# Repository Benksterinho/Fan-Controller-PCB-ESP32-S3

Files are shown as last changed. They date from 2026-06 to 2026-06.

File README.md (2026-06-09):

# JumboNAS Fan Controller PCB (ESP32-S3, Rev A)

This repository contains the hardware design and supporting documentation for a maker-friendly 4-wire PWM fan controller board built around ESP32-S3.

The PCB is intended for projects that need to power and control a standard 12 V PC fan, read tach feedback, and optionally show status on an SPI display, with room for future telemetry and expansion.

## What This Board Is For

- Controlling one 12 V 4-wire PWM fan from an ESP32-S3.
- Reading fan tach pulses for RPM measurement.
- Running standalone logic in CircuitPython on ESP32-S3.
- Driving an external ST7789 SPI display header.
- Exposing safe optional GPIOs through an expansion header.

Typical use cases:

- DIY NAS or homelab cooling controller.
- Smart enclosure or cabinet fan controller.
- General embedded fan-control bring-up platform.

## Hardware Overview

- Input power: 19-24 V DC recommended.
- Reverse polarity and surge protection at board input.
- 12 V rail: K7812 SIP module regulator.
- 3.3 V rail: K7803 SIP module regulator.
- Controller: ESP32-S3-WROOM-1-N16R8.
- Fan interface: Intel-style 4-pin PWM fan header.
- Programming/debug: external 1x6 UART header.

Input note:

- 19-24 V is the supported operating range for Rev A.
- 17-18 V may work in some conditions but is not guaranteed with the current Schottky protection stage.

## Project Status

Rev A is an actively developed hardware revision focused on first-pass manufacturability and bring-up reliability.

Current priorities:

- Keep BOM practical for PCBWay/LCSC assembly.
- Keep board size within cost-efficient limits (target under 99 x 99 mm).
- Use conservative, proven power-stage choices for a first hardware spin.

## Repository Layout

- [docs](docs): design rationale, requirements, BOM, sourcing, and build notes.
- [docs/sheet-specs](docs/sheet-specs): per-subsheet intent and signal definitions.
- [hardware/kicad/fan_controller_revA](hardware/kicad/fan_controller_revA): KiCad project files for Rev A.
- [firmware](firmware): reserved area for CircuitPython firmware and bring-up utilities.

## If You Want To Build One

1. Read [docs/requirements.md](docs/requirements.md) for scope and constraints.
2. Read [docs/architecture.md](docs/architecture.md) for system-level decisions.
3. Review [docs/bom-revA.csv](docs/bom-revA.csv) and [docs/bom-revA-status.md](docs/bom-revA-status.md).
4. Open the KiCad project in [hardware/kicad/fan_controller_revA](hardware/kicad/fan_controller_revA).
5. Follow manufacturing notes in [docs/pcbway-assembly.md](docs/pcbway-assembly.md).

## Key Docs

- [docs/architecture.md](docs/architecture.md)
- [docs/requirements.md](docs/requirements.md)
- [docs/current-budget.md](docs/current-budget.md)
- [docs/schematic-plan.md](docs/schematic-plan.md)
- [docs/gpio-map.md](docs/gpio-map.md)
- [docs/bom-revA.csv](docs/bom-revA.csv)
- [docs/bom-revA-status.md](docs/bom-revA-status.md)
- [docs/sourcing-checklist.md](docs/sourcing-checklist.md)
- [docs/pcbway-assembly.md](docs/pcbway-assembly.md)

## Safety And Scope

This is a low-voltage maker hardware project and is provided as-is. Validate thermal behavior, fan startup behavior, and input transient behavior in your own enclosure and power environment before unattended use.

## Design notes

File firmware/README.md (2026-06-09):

# Firmware Area

This folder is reserved for CircuitPython firmware, bring-up scripts, and test utilities for the ESP32-S3 controller.

Initial firmware goals:

- Fan PWM control
- Tach readback
- Wi-Fi telemetry receiver
- ST7789 display updates
- Optional expansion-header support

## Bring-Up Notes And Gotchas

### PWM Inversion Behavior

Fan PWM and display backlight use NPN open-collector stages, so logic is inverted at the controlled node.

```c
fan_duty = 1.0f - desired_speed;
bl_duty = 1.0f - desired_brightness;
```

### GPIO Warnings

- GPIO35/GPIO36/GPIO37 are reserved on N16R8 modules (internal PSRAM interface) and must not be reassigned.
- GPIO46 must not be driven HIGH during reset; doing so can force Download Boot instead of normal SPI boot.
- GPIO19/GPIO20 correspond to native USB D-/D+ on ESP32-S3; using them on expansion functions blocks future native USB reuse.

### External UART Wiring Reminder

Cross TX/RX between adapter and board:

- Adapter RX -> Board UART_TX
- Adapter TX -> Board UART_RX

This crossover is expected and is a common bring-up mistake.

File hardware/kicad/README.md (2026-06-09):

# KiCad Project Area

This folder contains KiCad-related project notes and guides for the fan controller.

## Active project folder

- `fan_controller_revA/`

## Inside `fan_controller_revA/`

- no active schematic files are currently committed
- how-to guides for rebuilding capture order and net naming
- local README with capture order and shared net names

## Next step

Create a fresh KiCad schematic project and capture each subsystem in the documented order.

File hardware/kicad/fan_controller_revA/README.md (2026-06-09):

# Fan Controller Rev A - KiCad Notes

Generated schematic files were removed. This folder now serves as the capture guide and naming reference.

## Files

- howto_subsheets/ (step-by-step capture guides)
- pcb_layout/ (subsheet-specific PCB Editor placement and routing guides)
- README.md (capture order and shared net naming)

## Capture Order

1. InputProtection
2. Power12V
3. Power3V3
4. ESP32S3Core
5. Fan4Wire
6. DisplayHeader_ST7789
7. ExternalProgrammingHeader
8. TestPoints
9. OptionalExpansionHeader

## Global Net Names To Reuse

- VIN_PROTECTED
- 12V
- 3V3
- GND
- EN_RESET
- GPIO0_BOOT
- UART_TX
- UART_RX
- FAN_PWM
- FAN_TACH
- SPI_SCK
- SPI_MOSI
- DISP_CS
- DISP_DC
- DISP_RST

## Notes

- Recreate all schematic sheets from docs/sheet-specs/*.md.
- Keep net names aligned with this README to avoid cross-sheet drift.
- Onboard rail telemetry is deferred from Rev A; add it only in a later revision if bring-up shows a real need.

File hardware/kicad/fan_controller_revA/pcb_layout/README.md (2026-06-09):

# PCB Layout Subsheet Guide Index

This folder contains PCB Editor placement/routing guides mapped to the schematic subsheets.

Use this flow after every schematic update:
1. In Schematic Editor, run Update PCB from Schematic.
2. In PCB Editor, refresh ratsnest and run DRC after major placement steps.
3. Work one subsheet cluster at a time using the matching file below.

## Absolute beginner quick start
1. Open PCB Editor and enable the right sidebar panels so Search/Filter tools are visible.
2. Open 00_SheetSelection_AfterUpdate.md and select one subsheet cluster first.
3. Move selected footprints with M, rotate with R, and place with left click.
4. Start routing with X, click to place corners, and double-click to finish a track.
5. Press B to refill copper zones after major routing edits.
6. Run DRC from the Inspect menu after each phase.

## Common PCB Editor shortcuts
1. M: Move selected footprint or item.
2. R: Rotate selected footprint or item.
3. E: Open properties for selected item.
4. Del: Delete selected item.
5. X: Route tracks.
6. V: Drop a via while routing.
7. B: Refill all zones.
8. Ctrl+S: Save.

If a shortcut differs in your KiCad version, open Preferences -> Hotkeys and search by command name.

## Files
- 00_SheetSelection_AfterUpdate.md
- 01_InputProtection_layout.md
- 02_Power12V_layout.md
- 03_Power3V3_layout.md
- 04_ESP32S3Core_layout.md
- 05_Fan4Wire_layout.md
- 06_DisplayHeader_ST7789_layout.md
- 07_ExternalProgrammingHeader_layout.md
- 08_TestPoints_layout.md
- 10_OptionalExpansionHeader_layout.md
- 11_EndToEnd_PCB_Layout_Checklist.md

## Recommended layout order
1. 11_EndToEnd_PCB_Layout_Checklist.md
2. 00_SheetSelection_AfterUpdate.md
3. 01_InputProtection_layout.md
4. 02_Power12V_layout.md
5. 03_Power3V3_layout.md
6. 04_ESP32S3Core_layout.md
7. 05_Fan4Wire_layout.md
8. 06_DisplayHeader_ST7789_layout.md
9. 07_ExternalProgrammingHeader_layout.md
10. 08_TestPoints_layout.md
11. 10_OptionalExpansionHeader_layout.md

## Placement strategy summary
1. Place power entry and protection near board input edge.
2. Keep regulator loops compact before placing digital logic.
3. Place ESP32 module for RF keepout first, then fan/display/programming connectors.
4. Reserve board edges for external connectors and test points.
5. Route high-current and noisy nets before sensitive digital feedback nets.

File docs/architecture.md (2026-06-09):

# Architecture

## Power

- Input protection front-end (screw terminal → reverse-polarity diode → fuse → VIN_PROTECTED)
- 12V rail: K7812-1000R3 non-isolated module regulator, SIP-3, 1A — no discrete magnetics or feedback network
- 3.3V rail: EVISUN K7803-1000R3 non-isolated module regulator, SIP-3, 1A — no discrete magnetics or feedback network
- Both modules (K7812 for 12V, K7803 for 3.3V) source directly from VIN_PROTECTED (19-24V supported input) in parallel. This avoids cascading and ensures each rail is independently regulated from the protected input. With the current Schottky reverse-polarity stage, 17-18V operation is not guaranteed.
- Decoupling caps on input and output of each module; no other external components required
- First-pass current budget: 12V rail 1A continuous, 3.3V rail 1A continuous with Wi-Fi burst headroom
- Module choice rationale: eliminates inductor/diode/feedback layout risk on Rev A; priority is first-pass success

## Control

- ESP32-S3-WROOM-1-N16R8 as the preferred module choice for Rev A if PCBWay sponsorship and sourcing allow it
- 16 MB flash and 8 MB PSRAM for CircuitPython headroom, buffer space, and future firmware growth
- Use the standard Espressif module footprint and keep the antenna keep-out clear
- If cost or sourcing pressure is significant, downgrade to an ESP32-S3 WROOM-1 PSRAM variant with less flash rather than changing the module family
- ESP32-S3 module with stable boot/reset wiring
- Fan PWM driven as open-drain compatible control
- Tach input protected and level-safe for 3.3V GPIO

## Interfaces

- External UART programming header (1x6, 2.54mm) for flashing and logging via external downloader
- External SPI display header
- Optional expansion header using only safe GPIOs

## Future Revision Note

- Onboard rail telemetry is intentionally deferred from Rev A. Test points cover bring-up needs, and a telemetry block can be added in a later revision if real diagnostic value appears.

## Layout rules

- Keep the board below the pricing threshold by budgeting to a smaller outline early
- Place power modules with input/output decoupling caps within 10mm of module pins
- Keep switch-node concerns eliminated — modules have no exposed switching nodes
- Reserve clear access for screw terminal and external programming header
- Antenna keep-out clear of copper under ESP32-S3 module

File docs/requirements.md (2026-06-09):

# Requirements

## Core

- Input: 19-24V DC supported for Rev A with current Schottky reverse-polarity stage; 17-18V operation is not guaranteed
- Outputs: 12V fan rail and 3.3V logic rail
- Controller: ESP32-S3 running CircuitPython
- Fan: one 4-pin PWM fan channel with tach feedback
- Display: external 3.3V SPI ST7789 header
- Connectivity: Wi-Fi telemetry from a Linux host

## Optional

- Maker expansion header for safe unused ESP32-S3 GPIOs

## Constraints

- Board outline should remain below 99x99 mm
- Prefer parts with strong public reference designs
- Prefer full PCBWay assembly with no user soldering

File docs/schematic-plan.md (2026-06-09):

# Schematic Plan

## Current Lock State

- LOCKED: ESP32S3Core (module selection, EN/BOOT network, and exported control nets)
- LOCKED: Fan4Wire (connector choice, PWM sink stage, tach conditioning, and root integration)
- LOCKED: DisplayHeader_ST7789 (live-verified sourcing for J_DISP, 33R damping network, optional MISO link, local bypass, and BL open-collector stage)
- LOCKED: ExternalProgrammingHeader (1x6 external UART/programming header with EN/GPIO0 control nets)
- VALIDATED: Fresh root ERC passes with 0 errors on current schematic set

## Top-Level KiCad Hierarchy

- `fan_controller_revA` as the root sheet
- `InputProtection` with [InputProtection spec](sheet-specs/InputProtection.md)
- `Power12V` with [Power12V spec](sheet-specs/Power12V.md)
- `Power3V3` with [Power3V3 spec](sheet-specs/Power3V3.md)
- `ESP32S3Core` with [ESP32S3Core spec](sheet-specs/ESP32S3Core.md)
- `Fan4Wire` with [Fan4Wire spec](sheet-specs/Fan4Wire.md)
- `DisplayHeader_ST7789` with [DisplayHeader_ST7789 spec](sheet-specs/DisplayHeader_ST7789.md)
- `ExternalProgrammingHeader` with [ExternalProgrammingHeader spec](sheet-specs/ExternalProgrammingHeader.md)
- `OptionalExpansionHeader` with [OptionalExpansionHeader spec](sheet-specs/OptionalExpansionHeader.md)
- `TestPoints` with [TestPoints spec](sheet-specs/TestPoints.md)

## Net Flow

1. `J1` input connector enters `InputProtection`
2. Protected VIN feeds `Power12V` and `Power3V3` in parallel
3. Regulated 12V feeds the fan power pin path
4. Regulated 3.3V feeds `ESP32S3Core`, `DisplayHeader_ST7789`, and safe expansion power
5. `ESP32S3Core` controls `Fan4Wire` via PWM and reads tach back from the fan interface
6. `ESP32S3Core` talks to `ExternalProgrammingHeader` for flashing/logging and to `DisplayHeader_ST7789` via SPI
7. `OptionalExpansionHeader` stays decoupled from the mandatory control path except for shared 3.3V, GND, and safe GPIO nets
8. `TestPoints` taps only stable rails and debug nets; it must not alter control behavior

## Sheet Boundaries

- `InputProtection`: connector, reverse protection, fuse, TVS, input filtering
- `Power12V`: K7812 module stage, input decoupling, 12V rail distribution
- `Power3V3`: K7803 module stage, input/output decoupling, 3.3V rail distribution
- `ESP32S3Core`: module, boot/reset, UART0, and mandatory control GPIO assignment
- `Fan4Wire`: 4-pin fan header, PWM open-drain drive, tach input conditioning, fan power pin
- `DisplayHeader_ST7789`: SPI display header and any series damping parts
- `ExternalProgrammingHeader`: external downloader interface exposing UART/EN/BOOT plus 3V3/GND
- `OptionalExpansionHeader`: safe spare GPIO header with per-line protection
- `TestPoints`: labeled rail and debug points for bring-up

## Capture Order

1. Lock `InputProtection` and power entry
2. Capture `Power12V` around the chosen reference layout
3. Capture `Power3V3` around the chosen reference layout
4. Capture `ESP32S3Core` and boot/reset wiring
5. Add `Fan4Wire`
6. Add `DisplayHeader_ST7789`
7. Add `ExternalProgrammingHeader`
8. Add `TestPoints`
9. Add `OptionalExpansionHeader` only after the mandatory path is stable

## Archived Sheet Note

- `ProgrammingUSB` is retained in the repository for reference only and is not part of the active Rev A signal path.

## Future Revision Note

- Onboard rail telemetry is deferred from Rev A. If bring-up or long-term diagnostics show a real need, add it in a later revision rather than reserving GPIOs and BOM lines now.

## Rules

- Do not use unvetted values for module-decoupling passives
- Keep module input/output decoupling close to module pins per datasheet
- Keep all user-facing headers clear of boot-strap pins and other sensitive ESP32-S3 lines
- Make sure every required part can be assembled by PCBWay without end-user soldering
- Use subsheets to review and lock one subsystem at a time instead of capturing the entire board as one block

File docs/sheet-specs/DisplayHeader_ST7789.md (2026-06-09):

# Sheet Spec: DisplayHeader_ST7789

**KiCad sheet:** `DisplayHeader_ST7789`  
**Purpose:** 2.54mm pin header for ST7789 SPI display module, series damping resistors, and display reset/backlight lines.  
**Input nets:** `3V3`, `GND`, `SPI_SCK`, `SPI_MOSI`, `DISP_CS`, `DISP_DC`, `DISP_RST`, `DISP_BL` (all from ESP32S3Core)  
**Connector output:** J_DISP — 8-pin 2.54mm right-angle through-hole header

---

## Display Module Compatibility

Target: generic ST7789 SPI display module (1.3", 1.54", or 2.0" breakout boards commonly sold as "ST7789 240×240" or "ST7789V 240×320").

**Typical ST7789 breakout pinout (8-pin, most common layout):**

| Pin | Label | Function |
|-----|---|---|
| 1 | GND | Ground |
| 2 | VCC | 3.3V power |
| 3 | SCL / SCK | SPI clock |
| 4 | SDA / MOSI | SPI data in |
| 5 | RES / RST | Hardware reset (active low) |
| 6 | DC / RS | Data/Command select |
| 7 | CS | Chip select (active low) |
| 8 | BLK / BL | Backlight enable |

**Note:** Pin order varies across ST7789 breakout vendors. The header is a pass-through — users plug their specific module. Label pins clearly in silk screen. Optional: provide a 2-row pinout label on silkscreen next to J_DISP.

---

## Connector (J_DISP)

| Parameter | Value |
|---|---|
| Type | 2.54mm pitch, 1x8 male header, right-angle, through-hole |
| Pins | 8 |
| PCBWay | THT, wave-solderable |
| Notes | No user soldering — PCBWay assembles. Rev A uses right-angle for lower vertical profile and side cable exit. |

---

## Series Damping Resistors

SPI signal lines should have series damping resistors to reduce ringing on fast edges (ST7789 can run at >20MHz SPI clock).

| Net | Resistor | Value | Package | Notes |
|-----|---|---|---|---|
| SPI_SCK | R_SCK | 33Ω | 0603 | Between ESP32 GPIO6 and J_DISP SCL pin |
| SPI_MOSI | R_MOSI | 33Ω | 0603 | Between ESP32 GPIO7 and J_DISP SDA pin |
| DISP_CS | R_CS | 33Ω | 0603 | Between ESP32 GPIO10 and J_DISP CS pin |
| DISP_DC | R_DC | 33Ω | 0603 | Between ESP32 GPIO9 and J_DISP DC pin |
| DISP_RST | R_RST | 33Ω | 0603 | Between ESP32 GPIO16 and J_DISP RES pin |

Rev A decision: SPI_MISO is not implemented. Leave any display-module MISO/SDO pin unconnected.

33Ω is a standard signal integrity value — low enough to not cause significant voltage drop, high enough to damp reflections at board edge.

---

## Power Lines to Header

| Header Pin | Net | Notes |
|---|-----|---|
| VCC | 3V3 | Directly from 3V3 rail; add 100nF bypass cap at header pin |
| GND | GND | Direct return |

**Local bypass cap:**
- 100nF MLCC, 10V, 0402, at J_DISP VCC pin.

Some ST7789 modules have a 3.3V regulator onboard and accept 5V VCC. This header provides 3.3V — confirm display module accepts 3.3V VCC (most bare ST7789 modules do).

## Rev A Verified Sourcing Picks

| Function | LCSC | Verified part |
|---|---|---|
| J_DISP | C32713267 | hanxia HX PZ2.54-1x8P WZ, 2.54mm single-row 1x8 male right-angle through-hole header |
| R_SCK / R_MOSI / R_CS / R_DC / R_RST | C2909394 | FOJAN FRC0603F33R0TS, 33Ω ±1% 0603 thick-film resistor |
| C_DISP_VCC | C307331 | Samsung CL05B104KB54PNC, 100nF 50V X7R 0402 MLCC |
| Q_BL | C181119 | MMBT3904 NPN SOT-23 for open-collector backlight sink |
| R_BL_BASE | C4190 | 2.2kΩ 0603 base resistor for Q_BL |
| R_BL_PD | C25803 | 100kΩ 0603 base pull-down for Q_BL |

---

## Backlight (BLK) Pin

Use the same open-collector approach as the fan PWM stage so the ESP32 does not source backlight current directly.

| Node | Implementation |
|---|---|
| Control input | `DISP_BL` from ESP32 GPIO40 into `R_BL_BASE` (2.2kΩ) to `Q_BL` base |
| Base default state | `R_BL_PD` (100kΩ) from `Q_BL` base to GND |
| Sink stage | `Q_BL` MMBT3904: emitter to GND, collector to J_DISP BLK pin |
| Backlight output | J_DISP BLK pin is driven by open-collector sink for on/off and PWM dimming |

**Firmware note:** This stage is inverting. Higher PWM duty at GPIO40 results in stronger sink action on BLK.

---

## Net Summary

| Net | Direction | Header Pin |
|-----|---|---|
| GND | Input | J_DISP pin 1 |
| 3V3 | Input | J_DISP pin 2 |
| SPI_SCK (via R_SCK) | Output | J_DISP pin 3 |
| SPI_MOSI (via R_MOSI) | Output | J_DISP pin 4 |
| DISP_RST (via R_RST) | Output | J_DISP pin 5 |
| DISP_DC (via R_DC) | Output | J_DISP pin 6 |
| DISP_CS (via R_CS) | Output | J_DISP pin 7 |
| DISP_BL (to Q_BL base via R_BL_BASE) | Output | Internal driver input |
| BLK (from Q_BL collector) | Output | J_DISP pin 8 |

---

## Layout Rules

1. **Damping resistors placed close to J_DISP**, between header and trace to ESP32 — correct side of the resistor should face the source (ESP32 side), termination faces the load (header).
2. **J_DISP placed on board edge or accessible face** for clean cable routing to display.
3. **Bypass cap at VCC pin** — immediately adjacent to J_DISP.
4. **SPI traces** should not run parallel to module power paths or fan 12V high-current traces. Keep at least 3mm separation where practical.
5. **RST trace** must not float — routed from ESP32 GPIO16 through R_RST to header pin. No pull-up needed (ESP32 drives it; display module typically has internal pull-up).

---

## Checklist Before KiCad Capture

- [ ] Confirm target display module pinout (measure or check datasheet for specific module)
- [ ] Verify right-angle connector pin-1 orientation matches silkscreen and cable pin order
- [ ] Verify display MISO/SDO pin remains NC in Rev A
- [ ] Verify BLK input behavior for your selected module (logic enable vs direct LED path)

---

## Dependencies

- **Depends on:** `ESP32S3Core` (SPI + CS/DC/RST nets), `Power3V3` (3V3 net)
- **Consumed by:** none (leaf sheet)

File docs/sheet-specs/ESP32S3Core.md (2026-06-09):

# Antenna Keep-Out Guidance (Critical)

**ESP32-S3-WROOM-1 PCB antenna keep-out requirements (for layout):**
- **No copper pours, traces, or fills** under the antenna section of the module (top 3.5mm × 18mm region; see module datasheet Figure 7).
- **No vias, test points, or silkscreen** in the keep-out zone.
- **No metal objects within 3mm** of antenna edges in the horizontal plane (including mounting hardware, shields, or connectors).
- **Place module at board edge** so antenna overhangs or is near the edge, per Espressif hardware design guidelines.
- **In KiCad:**
	- Draw a keep-out zone on the top copper, top mask, and top silkscreen layers for the antenna region.
	- Add a board edge keep-out annotation and a note in the layout file: "ESP32 antenna keep-out: no copper, no traces, no vias, no silkscreen, no test points."
	- Confirm keep-out is respected in DRC and final Gerbers.

# Sheet Spec: ESP32S3Core

**KiCad sheet:** `ESP32S3Core`  
**Purpose:** ESP32-S3 module mounting, boot/reset network, decoupling, GPIO assignment, and strapping pin safety.  
**Input nets:** `3V3`, `GND`  
**Output/exposed nets:** `UART_TX`, `UART_RX`, `GPIO0_BOOT`, `EN_RESET`, plus all GPIO signal nets to downstream sheets.  
**Reference:** ESP32-S3-WROOM-1 datasheet (Espressif DS0003), ESP32-S3 Technical Reference Manual

---

## Module Selection

| Parameter | Value |
|---|---|
| Module | ESP32-S3-WROOM-1-N16R8 (preferred) |
| Flash | 16MB external (N16) |
| PSRAM | 8MB Octal (R8) — required for CircuitPython heap |
| Antenna | On-module PCB antenna (no external RF components needed) |
| Package | SMD castellated edge, 2.54mm pitch |
| Footprint | ESP32-S3-WROOM-1 standard (52 pins) |
| Fallback | ESP32-S3-WROOM-1-N8R8 (8MB flash, same footprint) |

**Critical:** Do not substitute ESP32-S3-MINI — different footprint. Do not use ESP32-S3 bare die (requires RF layout expertise).

---

## Power Supply Pins

| Module pin | Net | Decoupling |
|---|-----|---|
| 3V3 (pin 2) | 3V3 | 10µF + 100nF MLCC at pin, on this sheet |
| GND (pins 1, 40, 41) | GND | All connected to ground plane |
| GND (EP / thermal pad) | GND | If exposed — solder to ground copper |

**Decoupling capacitors:**
- 1× 10µF MLCC, 10V, 0805, close to pin 2
- 1× 100nF MLCC, 10V, 0402, as close as possible to pin 2

These are in addition to any bulk cap on the 3V3 rail from Power3V3. Module datasheet requires local decoupling.

---

## Strapping Pins — Mandatory Safety Rules

Strapping pins determine boot mode and peripheral mapping at power-on. They are sampled once at reset. Wrong states = broken firmware uploads or non-boot.

| GPIO | Strapping Function | Required State | Implementation |
|---|---|---|---|
| GPIO0 | Download mode vs normal boot | HIGH = normal boot; LOW = download mode | 10kΩ pullup to 3V3; BOOT button pulls to GND |
| GPIO3 | JTAG source selection | HIGH = USB Serial/JTAG selected for deterministic behavior | 10kΩ pullup to 3V3 (`R_JTAG`), no functional load on net |
| GPIO45 | VDD_SPI voltage config | LOW = 3.3V (correct for this board) | 10kΩ pulldown to GND or leave at module default (confirm module default via datasheet §4.4) |
| GPIO46 | ROM messages | HIGH = enabled; LOW = suppressed | Leave at module default (internal pulldown); do not drive |

**Rules:**
- GPIO0, GPIO3, GPIO45, GPIO46 must NOT be routed to expansion headers or load circuits.
- GPIO0 is shared with BOOT button — no other load on this net except the 10kΩ pullup, external programming control path, and the BOOT button.
- Strapping pins are sampled at EN (reset) rising edge. Boot button footprint must short GPIO0 to GND.

---

## Boot/Reset Network

### EN (Reset) Pin
| Component | Value | Notes |
|---|---|---|
| R_EN | 10kΩ | Pullup from EN to 3V3 |
| C_EN | 1uF, 0603 | EN to GND — recommended typical value for clean power-on reset with 10k pull-up |
| RESET button | Momentary NO pushbutton | Shorts EN to GND via 0Ω (direct), footprint on board |
| EN_RTS | From ExternalProgrammingHeader sheet | External programmer reset control drives EN_RESET (active-low), with on-board RESET button as manual fallback |

External programming control wiring:
- Reset control line → EN_RESET (active-low)
- Boot control line → GPIO0_BOOT (active-low)

The active Rev A path is external via the `ExternalProgrammingHeader` sheet. Manual BOOT and RESET buttons remain valid for flashing.

### BOOT (Download Mode) Pin
| Component | Value | Notes |
|---|---|---|
| R_BOOT | 10kΩ | Pullup from GPIO0 to 3V3 |
| BOOT button | Momentary NO pushbutton | Shorts GPIO0 to GND |

Do not add a mandatory capacitor from GPIO0 to GND in Rev A. If a footprint is reserved for experiments, keep it DNP by default so it does not interfere with the Espressif auto-program timing.

---

## GPIO Assignments

### Used GPIOs (assigned on this sheet, nets exposed to other sheets)

| GPIO | Net name | Function | Destination sheet |
|---|---|---|---|
| GPIO4 | FAN_TACH | Tachometer input | Fan4Wire |
| GPIO5 | FAN_PWM | 25kHz PWM output (LEDC) | Fan4Wire |
| GPIO6 | SPI_SCK | SPI clock for display | DisplayHeader_ST7789 |
| GPIO7 | SPI_MOSI | SPI MOSI for display | DisplayHeader_ST7789 |
| GPIO9 | DISP_DC | Display D/C (data/command) | DisplayHeader_ST7789 |
| GPIO10 | DISP_CS | Display chip select | DisplayHeader_ST7789 |
| GPIO16 | DISP_RST | Display reset | DisplayHeader_ST7789 |
| GPIO40 | DISP_BL | Display backlight enable/PWM | DisplayHeader_ST7789 |
| GPIO43 | UART_TX | UART0 TX to external downloader | ExternalProgrammingHeader |
| GPIO44 | UART_RX | UART0 RX from external downloader | ExternalProgrammingHeader |

### Reserved / Do Not Use
| GPIO | Reason |
|---|---|
| GPIO11–GPIO15 | Internal to module (Octal PSRAM interface on N16R8) |
| GPIO35–GPIO37 | Internal to module on N16R8 variant; do not assign externally |
| GPIO0 | Strapping pin (BOOT) |
| GPIO3 | Strapping pin (JTAG) |
| GPIO45 | Strapping pin (VDD_SPI) |
| GPIO46 | Strapping pin (ROM messages) |

### Available for Expansion Header (OptionalExpansionHeader sheet)
Remaining free GPIOs after above assignments:
Safe candidates: GPIO1, GPIO2, GPIO17, GPIO18, GPIO19, GPIO20, GPIO21, GPIO38, GPIO39, GPIO41, GPIO42.

---

## Antenna Keep-Out Zone

The ESP32-S3-WROOM-1 PCB antenna extends from the top edge of the module.

**Keep-out requirements:**
- No copper pours, traces, or fills under the antenna section of the module (approximately the top 3.5mm × 18mm region per module datasheet Figure 7).
- No metal objects within 3mm of antenna edges in the horizontal plane.
- Module should be placed at board edge so antenna overhangs or is near the edge, per Espressif hardware design guidelines (ESP32-S3 Hardware Design Guidelines, Section 3).

**KiCad implementation:** Add a board edge keep-out zone annotation. Place module at board edge.

---

## Decoupling Summary (this sheet)

| Ref | Value | Package | Net | Placement |
|-----|---|---|-----|---|
| C_3V3_10U | 10µF MLCC, 10V | 0805 | 3V3 | At module VDD pin |
| C_3V3_100N | 100nF MLCC, 10V | 0402 | 3V3 | At module VDD pin, closer than 10µF |
| R_EN | 10kΩ | 0603 | EN to 3V3 | Near module |
| C_EN | 1uF | 0603 | EN to GND | Near module |
| R_BOOT | 10kΩ | 0603 | GPIO0 to 3V3 | Near module |
| SW_RESET | Tactile pushbutton | SMD, maker-friendly footprint | EN to GND | Panel edge |
| SW_BOOT | Tactile pushbutton | SMD, maker-friendly footprint | GPIO0 to GND | Panel edge |

---

## Net Boundaries (Sheet Interface)

**Inputs to this sheet:**
- `3V3` — from Power3V3
- `GND`

**Outputs / signals exposed at sheet boundary:**
- `UART_TX`, `UART_RX` → ExternalProgrammingHeader
- `EN_RESET` → ExternalProgrammingHeader
- `GPIO0_BOOT` → ExternalProgrammingHeader
- `FAN_PWM`, `FAN_TACH` → Fan4Wire
- `SPI_SCK`, `SPI_MOSI`, `DISP_CS`, `DISP_DC`, `DISP_RST`, `DISP_BL` → DisplayHeader_ST7789
- Free GPIOs → OptionalExpansionHeader

---

## Layout Rules

1. **Module placed at or near PCB edge** so antenna overhangs or clears board copper per keep-out rule.
2. **Boot/reset buttons on panel-accessible edge** — user must be able to press them for firmware updates.
3. **UART RX→TX/TX→RX** crossing must not create long loops — keep UART traces short from module to external programming header.
4. **Decoupling caps** placed as close as possible to VDD pin (under or adjacent to module).
5. **GPIO traces** for fan PWM, SPI, and UART should be kept away from module power routing and fan 12V high-current paths — minimum 3mm separation where practical.
6. **No vias through the antenna keep-out zone.**

---

## Checklist Before KiCad Capture

- [ ] Verify GPIO11-15 are locked to PSRAM in N16R8 module (check module datasheet Table 2-1)
- [ ] Verify GPIO45 strapping default for VDD_SPI in WROOM-1-N16R8 (should default LOW = 3.3V, confirm)
- [ ] Confirm GPIO4 and GPIO5 are not internally reserved in N16R8 variant
- [ ] Confirm EN/GPIO0 pull networks support both manual buttons and external programming control
- [ ] Download ESP32-S3-WROOM-1 KiCad footprint from Espressif component library or UltraLibrarian before starting capture

---

## Dependencies

- **Depends on:** `Power3V3` (3V3 net), `InputProtection` (GND, board-level supply stable)
- **Consumed by:** `Fan4Wire`, `DisplayHeader_ST7789`, `ExternalProgrammingHeader`, `OptionalExpansionHeader`

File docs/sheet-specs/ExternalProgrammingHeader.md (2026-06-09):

# Sheet Spec: ExternalProgrammingHeader

**KiCad sheet:** `ExternalProgrammingHeader`  
**Purpose:** Minimal external programming/debug interface for ESP32-S3 using an external downloader/USB-TTL adapter.  
**Input nets:** `3V3`, `GND`, `UART_TX` (from ESP32), `UART_RX` (to ESP32), `EN_RESET`, `GPIO0_BOOT`  
**Output:** 1x6 2.54mm right-angle through-hole header exposed for cable access

---

## Interface Decision (Rev A)

Rev A uses an external programming interface instead of an on-board USB-UART bridge. This removes high-speed USB routing, ESD/CC support circuitry, and bridge IC complexity from the PCB.

**Benefits:**
- Simpler layout and lower routing risk
- Fewer parts and faster bring-up iterations
- Compatible with many external programming adapters

**Trade-offs:**
- Requires an external cable/adapter for flashing and serial logs
- Correct cable wiring must be documented and followed

---

## Connector

| Parameter | Value |
|---|---|
| Type | Pin header, 1x6, 2.54mm pitch, right-angle, through-hole |
| Reference | `J_PROG` |
| Locked LCSC part | C42453955 (hanxia HX PZ2.54-1x6P WZ-P) |
| Assembly | THT (can be populated or left unpopulated for bench pads only) |
| Placement | Accessible board edge or service area |

Suggested pin order:

| Pin | Net | Direction | Notes |
|-----|-----|---|---|
| 1 | GND | Power return | Common ground |
| 2 | 3V3 | Power (optional target reference/power) | Use carefully if adapter powers target |
| 3 | UART_TX | Output from ESP32 | Connect to adapter RX |
| 4 | UART_RX | Input to ESP32 | Connect to adapter TX |
| 5 | EN_RESET | Control input (active-low) | External reset/program control |
| 6 | GPIO0_BOOT | Control input (active-low) | External boot strap control |

---

## External Downloader Wiring

Adapter to board mapping:
- Adapter RX -> `UART_TX`
- Adapter TX -> `UART_RX`
- Adapter GND -> `GND`
- Adapter 3V3 (optional) -> `3V3`
- Adapter reset/RTS control (if available) -> `EN_RESET`
- Adapter boot/DTR control (if available) -> `GPIO0_BOOT`

Manual flashing fallback (if control lines are unavailable):
1. Hold BOOT button
2. Press and release RESET
3. Release BOOT
4. Start upload/flash sequence

---

## Electrical Rules

1. `EN_RESET` and `GPIO0_BOOT` are active-low control nets.
2. Keep existing pull-up and button networks on ESP32S3Core unchanged.
3. Do not add heavy loads to `GPIO0_BOOT`.
4. Keep UART traces short and direct to reduce noise pickup.
5. If 3V3 is exposed, clearly document whether the external adapter is allowed to power the board.

---

## Net Summary

| Net | Direction | Notes |
|-----|---|---|
| `UART_TX` | Output from ESP32 | UART0 TX (GPIO43) |
| `UART_RX` | Input to ESP32 | UART0 RX (GPIO44) |
| `EN_RESET` | Input to ESP32 reset path | Active-low reset control |
| `GPIO0_BOOT` | Input to ESP32 boot strap path | Active-low boot control |
| `3V3` | Input/reference rail | Optional target power/reference |
| `GND` | Return | Shared ground |

---

## Layout Rules

1. Place `J_PROG` where probe clips/cables can be attached without blocking other connectors.
2. Keep silk pin-1 marker and pin labels clear and readable.
3. Route `EN_RESET` and `GPIO0_BOOT` away from noisy/high-current switching traces.
4. Keep UART traces away from fan 12V power loop where practical.

---

## Checklist Before KiCad Capture

- [ ] Confirm `J_PROG` pin numbering and silkscreen labels match cable convention
- [ ] Verify `UART_TX`/`UART_RX` directions are not swapped
- [ ] Verify `EN_RESET` and `GPIO0_BOOT` are exported at root and reachable from header
- [ ] Verify BOOT and RESET buttons remain functional for manual flashing
- [ ] Confirm external adapter workflow is documented for bring-up

---

## Dependencies

- **Depends on:** `ESP32S3Core` (UART and control nets), `Power3V3` (`3V3`)
- **Consumed by:** none (leaf sheet)

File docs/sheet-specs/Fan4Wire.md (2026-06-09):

# Sheet Spec: Fan4Wire

**KiCad sheet:** `Fan4Wire`  
**Purpose:** 4-pin PWM fan interface — power, ground, PWM open-collector sink drive, and tachometer input conditioning.  
**Input nets:** `12V`, `3V3`, `GND`, `FAN_PWM` (from ESP32S3Core), `FAN_TACH` (to ESP32S3Core)  
**Reference:** Intel 4-Wire PWM Fan Control Specification Rev 1.3

---

## Fan Connector (J_FAN)

| Parameter | Value |
|---|---|
| Connector type | 4-pin 2.54mm pitch single-row pin header (through-hole, right-angle) |
| Pinout (silkscreen)| 1: GND (black), 2: 12V (yellow), 3: TACH (green), 4: PWM (blue) |
| Pin 1 | GND |
| Pin 2 | 12V (fan power) |
| Pin 3 | TACH (open-collector out from fan, active low) |
| Pin 4 | PWM (25kHz control input to fan) |

**Standard Intel 4-pin fan pinout (for silkscreen and docs):**

| Pin | Signal | Color  | Function |
|-----|---|---|---|
| 1 | GND | Black  | Ground |
| 2 | 12V | Yellow | +12V (fan power) |
| 3 | TACH | Green  | Tachometer sense |
| 4 | PWM | Blue | PWM control input  |

**Silkscreen recommendation:**
- Label pin numbers and signals on PCB silkscreen: "1:GND 2:12V 3:TACH 4:PWM"
- Place pin 1 marker (dot or triangle) on silkscreen.

Use the project default connector: hanxia HX PZ2.54-1x4P WZ right-angle 2.54mm 1x4 THT pin header (`J_FAN`, LCSC `C32713263`).

---

## PWM Drive — Open-Collector Sink (Intel 4-Wire Compatible)

The fan PWM pin is a logic input with pull-up inside the fan (typically to 5V). Controller side must behave as an open-collector/open-drain sink and must not drive the pin high.

**Topology: NPN open-collector stage**

```
ESP32 FAN_PWM_GPIO ──[R_BASE 2.2kΩ]── Base (Q1: MMBT3904)
                   │
                 [R_BPD 100kΩ]
                   │
                  GND

Q1 Emitter ── GND
Q1 Collector ── FAN_PWM_OC ── Fan pin 4 (PWM)
```

When GPIO is high, Q1 sinks the PWM pin low. When GPIO is low, Q1 is off and fan internal pull-up provides logic high. This is an inverting stage; firmware should invert PWM duty convention if needed.

Do not add an external pull-up to 12V on fan PWM pin.

| Component | Value | Notes |
|---|---|---|
| Q1 (MMBT3904) | NPN transistor, SOT-23 | Open-collector sink stage for PWM pin |
| R_BASE | 2.2kΩ, 0603 | Limits base current from ESP32 GPIO |
| R_BPD | 100kΩ, 0603 | Base pull-down keeps Q1 off during reset |

**MMBT3904 specs:** common low-cost NPN in SOT-23, suitable for low-current logic sinking.

---

## Tachometer Input Conditioning

Fan tachometer output is open-collector (NPN), active-low, ~2 pulses per revolution.

**Conditioning circuit:**

```
Fan pin 3 (TACH) ──[R_TACH_PU 10kΩ]── 3V3
                │
               [R_SERIES 1kΩ]
                │
              FAN_TACH ── ESP32 GPIO4 (input)
                │
      [D_TACH_CLAMP Schottky]
            cathode → 3V3, anode → FAN_TACH
```

- `R_TACH_PU` (10kΩ to 3V3): pull-up for the open-collector tach signal, keeps logic level high when fan is not pulling low.
- `R_SERIES` (1kΩ): series protection resistor — limits GPIO current in fault conditions and adds mild RC filtering with GPIO input capacitance.
- `D_TACH_CLAMP` (Schottky to 3V3): clamps over-voltage at the MCU-side tach node if a fan tach output does not behave as open-collector at 3.3V levels.
- ESP32 internal pull-down must be **disabled** — external pull-up is sufficient. Do not add a parallel pull-down.

| Component | Value | Notes |
|---|---|---|
| R_TACH_PU | 10kΩ, 0603 | Pull-up to 3V3 |
| R_TACH_SERIES | 1kΩ, 0603 | Series protection |
| D_TACH_CLAMP | Schottky diode, SOD-123 | Cathode to 3V3, anode to FAN_TACH (MCU side) |

**Frequency:** At 1000 RPM with 2 pulses/rev: ~33Hz. At 3000 RPM: ~100Hz. Well within ESP32 GPIO interrupt range.

---

## Decoupling / Bulk Cap on 12V Fan Power

Fan motor startup draws inrush current. Add a local bulk cap at the 12V power pin on the fan connector.

| Component | Value | Notes |
|---|---|---|
| C_FAN_BULK | 47µF, 25V electrolytic, SMD | Local to J_FAN pin 2 (25V minimum recommended for 12V rail margin) |
| C_FAN_HF | 100nF MLCC, 25V, 0402 | HF bypass at J_FAN pin 2 |

---

## Net Summary

| Net | Direction | Notes |
|-----|---|---|
| 12V | Input | Fan power (pin 2 of connector) |
| GND | Input | Fan return (pin 1 of connector) |
| FAN_PWM | Input (from ESP32) | 3.3V GPIO drives transistor base, 25kHz |
| FAN_TACH | Output (to ESP32) | Conditioned 3.3V tach signal, ~33–200Hz |
| FAN_PWM_OC | Internal | Open-collector node from Q1 collector to fan PWM pin 4 |

---

## Layout Rules

1. **Q1 placed close to fan connector PWM pin** to keep the open-collector node short.
2. **C_FAN_BULK placed immediately at J_FAN 12V pin.**
3. **FAN_TACH signal trace** kept away from fan PWM open-collector node to avoid capacitive coupling.
4. **R_TACH_PU close to fan connector** — minimizes stub length on the open-collector net.
5. **D_TACH_CLAMP close to ESP32 GPIO input side** (after R_TACH_SERIES) so clamp current does not flow through long traces.
6. **R_BASE and R_BPD** placed close to Q1 base.

---

## Checklist Before KiCad Capture

- [ ] Confirm MMBT3904 LCSC MPN and stock (preferred candidate: `C181119`; alternates: `C111113`, `C916374`)
- [ ] Verify target fan (Arctic P12 Pro PST CO) follows Intel 4-wire PWM input behavior with internal pull-up
- [ ] Confirm PWM inversion requirement in firmware (NPN sink stage is inverting)
- [ ] Check maximum fan tachometer pull-up voltage is 3V3 compatible (most PC fans: yes)

---

## Dependencies

- **Depends on:** `ESP32S3Core` (FAN_PWM, FAN_TACH nets), `Power12V` (12V net), `Power3V3` (3V3 for pull-ups)
- **Consumed by:** none (leaf sheet)

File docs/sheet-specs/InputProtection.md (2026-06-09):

# InputProtection Sheet Spec

## Purpose

Protect the board from reverse polarity, overcurrent, and input transients before the DC/DC power modules.

## Nets

- `VIN_RAW`: raw 19-24V supported input from the screw terminal connector (17-18V not guaranteed with current Schottky reverse-polarity stage)
- `VIN_PROTECTED`: protected input rail feeding both the 12V and 3.3V module stages in parallel
- `GND`: system ground

## Required Functions

- Reverse-polarity protection
- Input fuse or resettable protection element
- TVS clamp for transient suppression
- Input filtering with bulk and high-frequency decoupling

## Recommended Input Caps (Rev A)

- `C_IN_BYP`: 100nF/50V ceramic close to connector/diode output for high-frequency noise suppression
- `C_IN_BULK`: 100uF/50V electrolytic bulk reservoir across `VIN_PROTECTED` to `GND` for hot-plug and load-step stability
- Keep bulk capacitor polarity correct: `+` to `VIN_PROTECTED`, `-` to `GND`

## Fuse Policy (Rev A)

- Use a 2A/125V 1206 input fuse
- Fast-acting is acceptable for Rev A maker use
- Keep reverse-polarity and TVS protection; rely on external PSU current limiting for rare edge cases
- Current BOM selection is Littelfuse 0466002.NRHF (LCSC C3105), 2A/63V, 1206.

## Design Rules

- Place protection parts close to the input connector
- Keep the high-current loop short and wide
- Use only parts that are comfortable at the expected input voltage and current
- Do not let this sheet become a catch-all for unrelated power or logic parts

## Review Gate

- Confirm the protected rail stays stable under startup and unplug/replug events
- Run basic cold/warm startup checks to confirm normal operation
- Confirm the protection parts are PCBWay-assemblable and stockable in China

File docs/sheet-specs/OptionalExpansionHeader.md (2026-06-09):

# Sheet Spec: OptionalExpansionHeader

**KiCad sheet:** `OptionalExpansionHeader`  
**Status:** OPTIONAL — populate only if spare GPIOs are desired for future firmware expansion.  
**Purpose:** Expose safe spare ESP32-S3 GPIOs on a 2.54mm header with per-line ESD/overcurrent protection. Must not conflict with strapping pins or internally reserved GPIOs.  
**Input nets:** `3V3`, `GND`, and spare GPIO nets from `ESP32S3Core`

---

## Safety Rules (Non-Negotiable)

1. **Strapping pins (GPIO0, GPIO3, GPIO45, GPIO46) must never appear on this header.**
2. **Module-internal GPIOs (GPIO11–GPIO15 in N16R8 variant) must never be routed here.**
3. **All header GPIO lines must have ESD protection** — either TVS array or series resistors at minimum.
4. **3V3 on header is protected with a polyfuse** to prevent shorts from external devices from browning out the main board.

---

## Available GPIOs (after all prior assignments)

From ESP32S3Core assignment table, the following GPIOs are assigned to mandatory functions:
- GPIO4: FAN_TACH
- GPIO5: FAN_PWM
- GPIO6, GPIO7, GPIO8, GPIO9, GPIO10: SPI display/control
- GPIO16: **Display reset only (do not use for expansion header)**
- GPIO40: **Display backlight control only (do not use for expansion header)**
- GPIO43, GPIO44: UART0

Reserved / prohibited:
- GPIO0, GPIO3, GPIO45, GPIO46: strapping pins
- GPIO11–GPIO15: PSRAM interface (N16R8)
- GPIO16: **Assigned to display reset, not available for expansion header**
- GPIO40: **Assigned to display backlight control, not available for expansion header**

**Safe candidates for expansion header:**
GPIO17, GPIO18, GPIO19, GPIO20, GPIO21, GPIO38, GPIO39, GPIO41, GPIO42

GPIO1 and GPIO2 are available for expansion because onboard telemetry is deferred from Rev A.

**Recommendation:** Expose up to 8 GPIOs on the header: GPIO17–GPIO21 (5 pins) + GPIO38, GPIO39, GPIO41 (3 pins) = 8 GPIO pins. **Do not use GPIO16 or GPIO40.**

---

## Connector (J_EXP)

| Parameter | Value |
|---|---|
| Type | 2.54mm pitch, 2×5 female header (10 pins) |
| Rows | 2 rows × 5 pins |
| Pinout | 8 GPIO signals + 3V3 (protected) + GND |
| PCBWay | THT, wave-solderable |

Rev A locked pinout (2×5, standard 2.54mm header):

| Pin | Signal | Pin | Signal |
|-----|---|-----|---|
| 1 | GPIO17 | 2 | GPIO18 |
| 3 | GPIO19 | 4 | GPIO20 |
| 5 | GPIO21 | 6 | GPIO38 |
| 7 | GPIO39 | 8 | GPIO41 |
| 9 | 3V3 (protected) | 10 | GND |

GPIO1, GPIO2, and GPIO42 remain available at the MCU level for future revisions but are not routed to J_EXP in Rev A.

---

## ESD Protection

| Option | Implementation | Notes |
|---|---|---|
| A (recommended) | 24-line TVS array (e.g., PRTR5V0U2X per 2 lines, or USBLC6-4SC6) | Best protection, compact |
| B (simple) | 33Ω series resistors on each GPIO line | Limits fault current; no clamping |
| C (minimal) | No protection | Not recommended — external devices can damage ESP32 GPIO |

**Decision for rev A:** Option B — 33Ω series resistors on each GPIO. Simple, no additional ICs needed. Upgrade to TVS array in rev B if needed.

| Component | Value | Package | Qty | Notes |
|---|---|---|-----|---|
| R_EXP_n (×8) | 33Ω, 0603 | 0603 | 8 | One per GPIO line, between ESP32 net and header pin |

---

## 3V3 Power on Header (Protected)

If 3V3 is exposed on the header, it must be polyfuse-protected to prevent external loads from browning out the main board.

| Component | Value | Notes |
|---|---|---|
| F_EXP | 500mA polyfuse (resettable PTC) | 3V3 to J_EXP power pin(s) |

Polyfuse trips at >500mA sustained draw, protecting the 3.3V rail. Resets when current drops.

---

## DNP Strategy

If this sheet is not populated:
- All resistors and polyfuse are DNP.
- GPIO pads on J_EXP are left unconnected on the board.
- No firmware changes needed — unused GPIOs are floating inputs, which is benign.

---

## Layout Rules

1. **Series resistors** placed between ESP32 traces and J_EXP header (resistors close to header, not close to module).
2. **3V3 polyfuse** placed before the 3V3 pin on J_EXP.
3. **J_EXP placed on accessible board edge** for easy external wiring.
4. **All GPIO traces** routed away from module input/output power paths and fan 12V high-current routing. Minimum 3mm clearance where practical.
5. **No strapping GPIO traces** routed to or near this header area.

---

## Dependencies

- **Depends on:** `ESP32S3Core` (spare GPIO nets), `Power3V3` (3V3 net)
- **Consumed by:** none (leaf sheet)
- **Capture order:** last, after all mandatory sheets are stable

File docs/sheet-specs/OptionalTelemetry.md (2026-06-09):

# OptionalTelemetry

Onboard rail telemetry is deferred from Rev A.

Reasoning:
- Test points already cover bring-up and fault-checking needs.
- Removing telemetry keeps Rev A GPIO allocation, firmware scope, and BOM complexity tighter.
- If real diagnostic value appears during bring-up or later use, rail telemetry can return in a future revision.

Rev A guidance:
- Do not include an `OptionalTelemetry` sheet in the active schematic hierarchy.
- Do not reserve GPIOs or BOM lines for telemetry in Rev A.
- Keep this topic as a future-revision note, not an active capture task.

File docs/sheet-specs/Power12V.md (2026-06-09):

# Power12V Sheet Spec

## Purpose

Convert the protected 19-24V supported input into a stable 12V rail for the fan using a proven non-isolated module regulator.

## Nets

- `VIN_PROTECTED`: protected input from `InputProtection`
- `12V`: regulated 12V output rail
- `GND`: power ground return

## Module Selection

| Parameter | Value |
|---|---|
| Module family | K78xx-compatible non-isolated module regulator |
| Model | K7812 (or K7812-500, K7812-1000 variant) |
| Topology | Integrated switching regulator module |
| Input voltage range | 18V – 36V (using protected 19-24V supported input; 17-18V not guaranteed with current Schottky reverse-polarity stage) |
| Output voltage | 12V fixed |
| Output current | 1.0A nominal (sufficient for 12V fan rail with margin) |
| Efficiency | ~78–82% typical |
| Package | SIP-3 module form factor |

**Rationale:** Pre-designed module eliminates risk of design iteration on discretes (inductors, catch diodes, feedback networks). Proven by manufacturer. High first-pass success rate.

---

## Decoupling & Input/Output Filtering

### Input Side (VIN_PROTECTED)
| Component | Value | Notes |
|---|---|---|
| C12_IN_BULK | 100µF, 50V | Bulk decoupling, placed close to module VIN pin |
| C12_IN_BYP | 1µF ceramic, 50V | Input bypass in parallel with C12_IN_BULK |

### Output Side (12V)
| Component | Value | Notes |
|---|---|---|
| C12_OUT_BULK | 47uF, 25V | Bulk decoupling at K7812 VOUT; improves fan startup and PWM transient stability |
| C12_OUT_BYP | 100nF ceramic, 50V | Output bypass at K7812 VOUT to reduce switching noise and ripple |

Datasheet note: K7812-1000R3 family tables indicate a high allowable capacitive load (up to ~680uF for positive-output variants), so adding 47uF + 100nF at the output remains comfortably within typical limits.

---

## Design Rules

- Place module close to input and output connectors to minimize trace inductance
- Keep all decoupling capacitors adjacent to module pins (≤ 10mm trace runs preferred)
- Use ground plane for low-impedance return paths
- Follow module datasheet pin assignments for VIN, GND, and VOUT exactly
- Mount on flat area with adequate spacing for thermal vias if needed

---

## Net Connections

| Module Pin | Net | Notes |
|---|-----|---|
| VIN | VIN_PROTECTED | Input from InputProtection sheet |
| VOUT | 12V | Regulated 12V output to fan stage |
| GND (in/out) | GND | Common ground return |

---

## Review Gate

- Confirm module datasheet lists K7812 as compatible with the supported 19-24V input range (K7812 typical range 18-36V)
- Confirm output regulation spec is ±5% or better across full input and load range
- Verify PCBWay assembly supports selected SIP-3 module footprint (confirm with EMS lead time check)
- Measure 12V output voltage under load and thermal behavior during board bringup

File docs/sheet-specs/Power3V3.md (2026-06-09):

# Sheet Spec: Power3V3

**KiCad sheet:** `Power3V3`  
**Purpose:** Step down `VIN_PROTECTED` to 3.3V for all ESP32-S3 logic, display header, and peripherals using a proven non-isolated module regulator.  
**Input net:** `VIN_PROTECTED`  
**Output net:** `3V3`  

---

## Module Selection

| Parameter | Value |
|---|---|
| Module family | K78xx-compatible non-isolated module regulator |
| Model | K7803 (or K7803-500 variant) |
| Topology | Integrated switching regulator module |
| Input voltage range | Wide input range per datasheet (must include 19-24V VIN_PROTECTED for this design; 17-18V not guaranteed with current Schottky reverse-polarity stage) |
| VIN | VIN_PROTECTED | Input source for K7803 module (parallel topology; see architecture) |
| Output voltage | 3.3V fixed |
| Output current | 1.0A nominal (selected for Wi-Fi/display headroom) |
| Efficiency | ~75–80% typical |
| Package | SIP-3 module form factor |

**Current capacity note:** K7803 at 300–500mA provides margin for:
- ESP32-S3 average: 100–150mA typical
- Display header: 50–100mA typical  
- Wi-Fi burst transients: covered by bulk output cap
- Test margin: ~50–100mA headroom

If 3.3V rail draws exceed the measured safe headroom during Wi-Fi activity, evaluate a higher-current compatible module variant.

**Rationale:** Pre-designed module eliminates risk of design iteration on discrete inductors, catch diodes, and feedback networks. Proven by manufacturer. High first-pass success rate.

---

---

## Decoupling & Input/Output Filtering

### Input Side (VIN_PROTECTED from InputProtection)
| Component | Value | Notes |
|---|---|---|
| C33_IN_BULK | 100uF, 50V | Bulk input decoupling, placed close to module VIN pin |
| C33_IN_BYP | 10uF ceramic, 50V X5R, 1210 | Input bypass in parallel with C33_IN_BULK; 1210 size avoids unrealistic 0603-at-50V assumptions |

### Output Side (3.3V)
| Component | Value | Notes |
|---|---|---|
| C33_OUT_BULK | 100µF, 10V | Bulk output cap for transient margin during Wi-Fi bursts |
| C33_OUT_BYP | 10uF ceramic, 16V X5R, 0603 | Output bypass in parallel with C33_OUT_BULK |

---

## Design Rules

- Place module close to VIN_PROTECTED source (minimize trace inductance to module VIN pin)
- Place output capacitors (C33_OUT_BULK, C33_OUT_BYP) immediately adjacent to module output pin — keep leads short
- Use ground plane for low-impedance return paths (both input and output GND must connect to plane)
- Follow module datasheet pin assignments for VIN, GND, and VOUT exactly
- Mount module in flat area with adequate thermal vias under package if needed
- **No external inductors, catch diodes, or feedback resistor networks required — module is fully integrated.**

---

## Net Connections

| Module Pin | Net | Notes |
|---|-----|---|
| VIN | VIN_PROTECTED | Input from InputProtection sheet (parallel with K7812 stage) |
| VOUT | 3V3 | Regulated 3.3V output to ESP32-S3, display header, and peripherals |
| GND (in/out) | GND | Common ground return |

---

## Output Rail Spec

| Net | Voltage | Max current (module) | Downstream consumers |
|-----|---|---|---|
| 3V3 | 3.3V ± 3% | up to 1.0A module rating | ESP32-S3 module, display header, fan interface transistor bias network, external programming header (optional target power), test points, telemetry ADC, optional expansion header |

---

## Capacity & Contingency

**Current consumption summary (typical):**
- ESP32-S3 average: ~100–150mA
- Display refresh + GPIO: ~50–100mA  
- Wi-Fi TX burst: transient spikes (supported by C33_OUT_BULK cap ESR and series impedance)
- Margin: ~50–100mA available for future I/O expansion

**If 3.3V rail proves undersized after bringup:**
1. Measure peak current during Wi-Fi and SPI display refresh
2. If sustained output current approaches the module limit, evaluate:
   - A higher-current compatible module variant
   - Load reduction on optional rails
3. Update BOM and Power3V3 sheet accordingly

This is a **first-pass design assumption**; bringup will validate.

---

## Checklist Before KiCad Capture

- [ ] Confirm Mornsun K7803 LCSC part number and availability (typical LCSC search: "Mornsun K7803")
- [ ] Verify K7803 package/footprint compatibility with PCBWay assembly (SIP-3)
- [ ] Confirm 100uF/50V electrolytic input cap LCSC MPN (SMD)
- [ ] Confirm 100µF/10V electrolytic output cap LCSC MPN (SMD)
- [ ] Download K7803 datasheet; verify pin assignments match schematic net table
- [ ] Plan PCB layout: place module close to VIN_PROTECTED input routing

---

## Dependencies

- **Depends on:** `InputProtection` sheet (`VIN_PROTECTED` input net must be present)
- **Consumed by:** `ESP32S3Core`, `Fan4Wire`, `DisplayHeader_ST7789`, `ExternalProgrammingHeader`, `OptionalExpansionHeader`

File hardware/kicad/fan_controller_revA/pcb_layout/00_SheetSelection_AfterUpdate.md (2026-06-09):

# Select Subsheet Footprints After Full Schematic Update

Use this guide after Update PCB from Schematic so you can place one subsheet at a time in PCB Editor.

## Baseline sync flow
1. Save all schematic sheets.
2. Run Update PCB from Schematic.
3. Choose full update and keep existing placement only where intentional.
4. Open PCB Editor and confirm all new footprints exist.

## Absolute beginner: where to click first
1. In PCB Editor, turn on the right sidebar panels if hidden.
2. Open the Search/Filter area and set object type to Footprints.
3. Click once on any footprint, then press E to confirm metadata fields are present.
4. In the properties/details view, verify fields include Sheetname and Sheetfile.
5. Return to Search/Filter and use those fields to select one full subsheet cluster.

## Absolute beginner: move a selected cluster
1. After filtering, press Ctrl+A in the filtered list if needed to select all matches.
2. Press M to move the selected footprints as one group.
3. Move cursor to the target area and left click to place.
4. Press R before placing if the group orientation should rotate.
5. Repeat until each subsheet cluster has a rough floorplan position.

## Method A: select by sheet metadata (preferred)

KiCad footprints imported from hierarchical sheets carry two metadata fields: **Sheetname** and **Sheetfile**. You use these to select every footprint in one subsheet at once.

### Step-by-step: using Inspect → Board Statistics / Net Inspector is NOT the route. Use the Selection Filter + right-click menu instead.

#### Option A1 — Right-click "Select" menu (fastest, no typing)
1. Click on any footprint that you know belongs to the target subsheet (e.g. click D1 for InputProtection).
2. Right-click → **Select** → **All Footprints in Same Hierarchical Sheet**.
3. All footprints from that subsheet are now selected (highlighted).
4. Press **M** to move them as a group, left-click to place.
5. Press **Ctrl+S** to save.

> Shortcut summary: click one footprint → right-click → Select → All Footprints in Same Hierarchical Sheet → M → left-click → Ctrl+S

#### Option A2 — Inspect menu query (KiCad 7/8 with query filter)
1. Menu bar: **Inspect** → **Board Statistics** is not relevant here. Use instead:
2. Menu bar: **Edit** → **Find** (shortcut **Ctrl+F**).
3. In the Find toolbar at the bottom of the canvas, type the subsheet name e.g. `Fan4Wire`.
4. Change the search scope drop-down from "Reference" to **Sheet Name** (or "Hierarchical Sheet").
5. Click **Select All** or press **Enter** repeatedly to step through, then **Ctrl+A** to select all matches.
6. Press **M** to move the selected group.

> If the scope drop-down does not have "Sheet Name", use Option A1 or A3 instead.

#### Option A3 — Selection Filter + footprint properties filter (KiCad 8)
1. Open **View** → **Selection Filter** (or press **F6** / look for the panel bottom-right).
2. Ensure **Footprints** checkbox is ticked; untick all others to avoid grabbing tracks or zones.
3. On the canvas, hold **Ctrl** and rubber-band select the entire board area to grab all footprints.
4. With everything footprint-selected, open **Edit** → **Find** (**Ctrl+F**), type the subsheet name, and use **Select** to narrow.
   - Alternatively after step 3: right-click → **Select** → **Filter Selection** → filter field **Sheetname** = `Fan4Wire`.
5. Deselect footprints that do not match (Shift-click to remove individual items if needed).
6. Press **M** to move.

#### Option A4 — Scripting console one-liner (power users, KiCad 8)
1. Menu bar: **Tools** → **Scripting Console** (shortcut **Ctrl+`** on some builds).
2. Paste and run (replace `Fan4Wire` with the target sheet name):
   ```python
   import pcbnew; b=pcbnew.GetBoard()
   fps=[f for f in b.GetFootprints() if f.GetSheetname()=="Fan4Wire"]
   for f in fps: f.SetSelected()
   pcbnew.Refresh()
   ```
3. Return to the canvas; the matching footprints are now selected.
4. Press **M** to move as a group.

### Step-by-step example: select the Fan4Wire cluster (Option A1 recommended)
1. In PCB Editor, click any known Fan4Wire part — e.g. Q_FAN (the gate-drive transistor).
2. Right-click → **Select** → **All Footprints in Same Hierarchical Sheet**.
3. Confirm the status bar at the bottom shows multiple footprints selected.
4. Press **M**, move the group to the fan-connector corner, left-click to drop.
5. Press **Ctrl+S**.

### Sheet name values for this project
| Subsheet | Sheetname field | Sheetfile field |
|---|---|---|
| InputProtection | InputProtection | InputProtection.kicad_sch |
| Power12V | Power12V | Power12V.kicad_sch |
| Power3V3 | Power3V3 | Power3V3.kicad_sch |
| ESP32S3Core | ESP32S3Core | ESP32S3Core.kicad_sch |
| Fan4Wire | Fan4Wire | Fan4Wire.kicad_sch |
| DisplayHeader_ST7789 | DisplayHeader_ST7789 | DisplayHeader_ST7789.kicad_sch |
| ExternalProgrammingHeader | ExternalProgrammingHeader | ExternalProgrammingHeader.kicad_sch |
| TestPoints | TestPoints | TestPoints.kicad_sch |
| OptionalExpansionHeader | OptionalExpansionHeader | OptionalExpansionHeader.kicad_sch |

## Method B: select by reference list (fallback)
If Sheetname filtering is unavailable, use each subsheet guide reference list and multi-select by RefDes.

Practical tips:
1. Use Find to jump to each RefDes.
2. Add each footprint to the selection and move as one cluster.
3. Lock anchor parts after initial floorplan placement.
4. Good anchors to lock early are board-edge connectors and large modules.

## Method C: schematic cross-probing (fallback)
1. In Schematic Editor, open one subsheet.
2. Select symbols in that subsheet.
3. Use cross-probe to highlight linked footprints in PCB Editor.
4. Move highlighted footprints as a group.

## Quick troubleshooting
1. If nothing highlights, verify Update PCB from Schematic completed without skipped items.
2. If Sheetname field appears missing, test with Sheetfile or use RefDes fallback.
3. If only one footprint moves, you likely lost group selection; undo and reselect full filter result.
4. If ratsnest lines look chaotic, do not route yet; finish rough placement of all clusters first.

## Useful shortcuts during selection and placement
1. M: Move selected item/group.
2. R: Rotate selected item/group.
3. E: Open selected item properties.
4. Del: Remove accidentally placed item.
5. Ctrl+S: Save after each cluster placement.

## Sanity checks before routing
1. Every selected cluster belongs to exactly one subsheet.
2. Connectors are oriented for cable access and board edge clearance.
3. No footprint is left unplaced outside board outline.
4. Ratsnest lines mostly remain local to each cluster before final integration.

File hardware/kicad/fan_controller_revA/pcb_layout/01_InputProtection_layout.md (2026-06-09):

# InputProtection PCB Layout Guide

Target subsheet: InputProtection

## Footprints in this cluster
- J_PWR
- F1
- D1
- D_TVS_IN
- C_IN_BYP
- C_IN_BULK

## Select this subsheet after schematic update

### Fastest method: right-click → Select → All Footprints in Same Hierarchical Sheet
1. Click any known InputProtection footprint — e.g. **D1** or **F1** — on the canvas.
2. Right-click → **Select** → **All Footprints in Same Hierarchical Sheet**.
3. Status bar at the bottom should show multiple footprints selected (J_PWR, F1, D1, TVS, caps).
4. Press **M** to move the group, left-click to place.
5. Press **Ctrl+S** to save.

### Fallback: select RefDes list above as a group.

Key shortcuts: **M** move · **R** rotate · **E** properties · **Ctrl+S** save · **Ctrl+Z** undo.

## Placement intent
1. Put J_PWR on a board edge with screwdriver access.
2. Place D_TVS_IN immediately behind connector entry to clamp surges early.
3. Keep F1 and D1 in short series path from VIN_RAW to VIN_PROTECTED.
4. Place C_IN_BYP near connector/protection input side.
5. Place C_IN_BULK near VIN_PROTECTED handoff toward regulator area.

## Routing priorities
1. Route input current path first: J_PWR -> F1 -> D1 -> VIN_PROTECTED.
2. Use short, wide copper for high-current entry path and return.
3. Keep TVS path short and direct to ground reference.
4. Avoid routing sensitive digital traces through input-protection zone.

Beginner routing steps:
1. Press X to start routing from J_PWR VIN pad.
2. Click at each corner point to shape the path.
3. Double-click to finish the track.
4. Press B after finishing this area to refill copper zones.

## Placement done criteria
1. Protection chain is physically linear and readable.
2. VIN_RAW copper is short and constrained to entry area.
3. VIN_PROTECTED exits cleanly toward both power regulators.

## Silkscreen visibility recommendation (space-saving)
1. Keep visible on F.SilkS: J_PWR1, F1, D1, D_TVS_IN1, C_IN_BULK1.
2. Hide on F.SilkS when crowded: C_IN_BYP1 (keep it visible on F.Fab).
3. Add short functional text near the block: VIN IN, VIN PROT, GND.

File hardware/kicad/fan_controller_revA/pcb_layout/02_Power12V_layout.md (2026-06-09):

# Power12V PCB Layout Guide

Target subsheet: Power12V

## Footprints in this cluster
- U1
- C12_IN_BULK
- C12_IN_BYP
- C12_OUT_BULK
- C12_OUT_BYP

## Select this subsheet after schematic update

### Fastest method: right-click → Select → All Footprints in Same Hierarchical Sheet
1. Click any known Power12V footprint — e.g. **U1** — on the canvas.
2. Right-click → **Select** → **All Footprints in Same Hierarchical Sheet**.
3. Confirm U1 and all support capacitors are highlighted.
4. Press **M** to move, **R** to rotate for best pin direction, left-click to place.
5. Press **Ctrl+S** to save.

### Fallback: select the RefDes list above as one group.

Key shortcuts: **M** move · **R** rotate · **E** properties · **Ctrl+S** save · **Ctrl+Z** undo.

## Placement intent
1. Place U1 close to the protected-input distribution path from InputProtection.
2. Keep C12_IN_BULK and C12_IN_BYP tight to U1 VIN/GND pins.
3. Keep C12_OUT_BULK and C12_OUT_BYP tight to U1 VOUT/GND pins.
4. Leave space for thermal relief and airflow around U1.

## Routing priorities
1. Route compact input loop: VIN_PROTECTED -> U1 -> input caps -> GND return.
2. Route compact output loop: U1 VOUT -> output caps -> GND return.
3. Keep 12V trunk short from U1 output toward Fan4Wire.
4. Keep ground return low impedance and avoid narrow choke points.

Beginner routing steps:
1. Press X and route VIN_PROTECTED into U1 first.
2. Route U1 to nearest input caps next.
3. Route VOUT to output caps, then to 12V trunk.
4. Press B to repour zones and inspect current path shape.

## Placement done criteria
1. Input/output capacitor loops around U1 are visibly compact.
2. 12V handoff direction toward fan cluster is obvious.
3. No long detours in VIN_PROTECTED or 12V high-current paths.

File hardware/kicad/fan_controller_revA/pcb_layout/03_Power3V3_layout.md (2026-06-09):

# Power3V3 PCB Layout Guide

Target subsheet: Power3V3

## Footprints in this cluster
- U2
- C33_IN_BULK
- C33_IN_BYP
- C33_OUT_BULK
- C33_OUT_BYP

## Select this subsheet after schematic update

### Fastest method: right-click → Select → All Footprints in Same Hierarchical Sheet
1. Click any known Power3V3 footprint — e.g. **U2** — on the canvas.
2. Right-click → **Select** → **All Footprints in Same Hierarchical Sheet**.
3. Confirm U2 plus all input/output capacitors are selected.
4. Press **M** to move, **R** to rotate so VIN side faces input path, left-click to place.
5. Press **Ctrl+S** to save.

### Fallback: select the RefDes list above as one group.

Key shortcuts: **M** move · **R** rotate · **E** properties · **Ctrl+S** save · **Ctrl+Z** undo.

## Placement intent
1. Place U2 near VIN_PROTECTED distribution but separated from noisy fan-current zone.
2. Place C33_IN_BULK and C33_IN_BYP tight to U2 VIN/GND.
3. Place C33_OUT_BULK and C33_OUT_BYP tight to U2 VOUT/GND.
4. Reserve clean 3V3 fan-out corridor toward ESP32, display, and programming header.

## Routing priorities
1. Keep VIN input loop short and wide enough for regulator current.
2. Keep 3V3 output loop compact before branching to loads.
3. Route main 3V3 trunk first, then branch to subsystems.
4. Keep digital clock/control traces away from regulator input loop where possible.

Beginner routing steps:
1. Press X and route VIN_PROTECTED to U2.
2. Connect input capacitors directly to VIN/GND near U2 pins.
3. Route U2 output to output capacitors first, then extend 3V3 trunk.
4. Refill zones with B and verify no thin bottleneck on 3V3 trunk.

## Placement done criteria
1. 3V3 source and decoupling form a compact power island.
2. 3V3 trunk leaves island cleanly toward digital clusters.
3. Return current path to ground plane is direct and low impedance.

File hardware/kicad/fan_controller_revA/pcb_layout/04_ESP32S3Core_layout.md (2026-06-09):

# ESP32S3Core PCB Layout Guide

Target subsheet: ESP32S3Core

## Footprints in this cluster
- U3
- C_BULK
- C_DEC
- R_EN
- R_BOOT
- R_JTAG
- C_EN
- SW_RESET
- SW_BOOT

## Select this subsheet after schematic update

### Fastest method: right-click → Select → All Footprints in Same Hierarchical Sheet
1. Click any known ESP32S3Core footprint — e.g. **U3** — on the canvas.
2. Right-click → **Select** → **All Footprints in Same Hierarchical Sheet**.
3. Confirm U3 and all support capacitors, resistors, and switches are highlighted.
4. Press **M** to move, **R** to rotate so antenna side faces board edge, left-click to place.
5. Press **Ctrl+S** to save.

### Fallback: select RefDes list above, then move as one cluster.

Key shortcuts: **M** move · **R** rotate · **E** properties · **Ctrl+S** save · **Ctrl+Z** undo.

## Placement intent
1. Place U3 so antenna edge faces board edge with no copper under keepout.
2. Place C_DEC closest to the U3 3V3 pin entry, with C_BULK immediately behind it on the same 3V3 branch.
3. Keep EN and BOOT support parts (R_EN, C_EN, SW_RESET, R_BOOT, SW_BOOT) near their target pins.
4. Keep strap support R_JTAG local to U3 IO3 with no extra branch stubs.
5. Place reset and boot buttons at an accessible board-edge area.
6. Reserve a solid local ground region around the module body so the side GND pads and bottom GND pad array connect into the same low-impedance return.

## Detailed placement order
1. Lock U3 orientation first: antenna to the board edge, pin 1 corner easy to inspect, enough room on the non-antenna sides for decoupling and strap parts.
2. Place C_DEC first. It should be the closest 3V3 bypass part to the module supply pin, with the shortest possible loop from 3V3 pin to capacitor to ground.
3. Place C_BULK next to C_DEC, still very close to U3, but let C_DEC be the innermost part.
4. Place R_EN and C_EN as a tight pair near EN. Keep the EN node compact so it is not a long noise-sensitive trace.
5. Place R_BOOT near GPIO0. Put SW_BOOT near the board edge, but do not force the GPIO0 trace to wander around the button footprint.
6. Place R_JTAG near IO3 and keep that net local. Do not use this area as a convenient routing lane for unrelated signals.
7. Place SW_RESET near the same accessible edge area as SW_BOOT so bring-up and recovery are straightforward.

## Bottom GND pad handling under U3
1. U3 includes a bottom GND pad array on pad 41. Treat that area as part of the main RF and return structure, not as optional mechanical copper.
2. Do not route signal traces through the pad-41 area on the top layer.
3. Tie the pad-41 array into a solid top-layer ground region that also joins the module side GND pads. Avoid thin neck-down traces between ground pads.
4. Give C_DEC and C_BULK a very short ground return into this local ground region so their current loop closes at the module, not through a longer plane detour.
5. Add several nearby GND stitching vias around the pad array to connect top-layer ground to the bottom-layer ground plane. Place them just outside the pad field or in open gaps allowed by the footprint and assembly process.
6. If your manufacturer does not support filled/capped via-in-pad, do not drop open vias directly in the exposed pad paste area. Use adjacent stitching vias instead.
7. Keep solder-mask, paste, and copper settings from the library footprint unless you have a datasheet-backed reason to change them.
8. Do not use thermal relief between the bottom GND pad region and the local top-layer ground copper unless assembly or rework constraints force it. Lowest practical impedance matters more here.
9. Keep the bottom GND pad region out of the antenna keepout. The pad field should connect strongly to ground, but the antenna zone must stay clear of copper.

## Antenna and keepout details
1. Keep all copper, vias, pours, and test pads out of the antenna keepout area at the antenna end of U3.
2. Do not place buttons, tall headers, shielding cans, or cable metal near the antenna end.
3. If the board edge is directly under the antenna end, prefer a clean board edge over decorative cut-ins or dense silkscreen in that area.
4. Do not route the 3V3 trunk, fan-current returns, or dense SPI bundles across the antenna keepout boundary.

## Routing priorities
1. Route 3V3 and GND to U3 first with the shortest practical paths and with the decoupling loop completed before branching 3V3 elsewhere.
2. Finish the local ground strategy around U3 early: side GND pads, bottom pad array, and nearby stitching vias.
3. Route critical control nets EN_RESET and GPIO0_BOOT cleanly to the programming-header area.
4. Route the SPI group as a tidy bundle toward the display header cluster, with similar path length and minimal unnecessary layer changes.
5. Keep FAN_TACH away from PWM and switching-noise corridors.
6. Keep strap pins and reserved pins free from accidental coupling or opportunistic reuse.

Beginner routing steps:
1. Start with X from the U3 3V3 pin to C_DEC, then from that same local node to C_BULK.
2. Connect C_DEC and C_BULK grounds directly into the local U3 ground region before routing other signals.
3. Pour or route the U3 local top-layer ground so pad 1, pad 40, and pad-41 array all share a short return.
4. Drop nearby GND stitching vias once the local ground shape is clear.
5. Route EN_RESET and GPIO0_BOOT before less critical IO.
6. Route SPI lines as a grouped bundle in the same general corridor.
7. Add vias with V only when needed; fewer vias are easier to debug, except for deliberate GND stitching around U3.
8. Press B after major routing steps so you can verify the antenna keepout and local ground continuity are still correct.

## Quick review checklist for refs and placement
1. The guide uses the new uppercase shortened names: C_BULK, C_DEC, R_EN, R_BOOT, R_JTAG, C_EN, SW_RESET, SW_BOOT.
2. C_DEC is closer to the U3 power entry than C_BULK.
3. R_EN plus C_EN are tight to EN, and R_BOOT is tight to GPIO0.
4. R_JTAG is local to IO3 with no functional load attached.
5. The U3 bottom GND pad array is tied into a solid local ground region with nearby stitching vias.
6. No copper or vias violate the antenna keepout.

## Placement done criteria
1. RF keepout is preserved and not overlapped by copper or metal.
2. Decoupling caps are tightly coupled to U3 supply pins and return directly into the local module ground.
3. The bottom GND pad array and side GND pads form one clean, low-impedance ground structure.
4. Boot/reset and programming control nets are short and unambiguous.

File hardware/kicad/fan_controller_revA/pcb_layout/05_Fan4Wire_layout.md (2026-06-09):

# Fan4Wire PCB Layout Guide

Target subsheet: Fan4Wire

## Footprints in this cluster
- J_FAN
- Q1
- R_BASE
- R_BPD
- R_TACH_PU
- R_TACH_SERIES
- D_TACH_CLAMP
- C_FAN_BULK
- C_FAN_HF

## Select this subsheet after schematic update

### Fastest method: right-click → Select → All Footprints in Same Hierarchical Sheet
1. Click any known Fan4Wire footprint — e.g. **J_FAN** or **Q1** — on the canvas.
2. Right-click → **Select** → **All Footprints in Same Hierarchical Sheet**.
3. Confirm J_FAN, Q1, and tach parts are highlighted.
4. Press **M** to move the cluster to the board-edge fan-connector area, **R** to rotate until connector pins match cable direction, left-click to place.
5. Press **Ctrl+S** to save.

### Fallback: select RefDes list above as one cluster.

Key shortcuts: **M** move · **R** rotate · **E** properties · **Ctrl+S** save · **Ctrl+Z** undo.

## Placement intent
1. Put J_FAN on board edge for cable strain relief and access.
2. Place C_FAN_BULK and C_FAN_HF near J_FAN 12V/GND pins.
3. Place Q1 + R_BASE + R_BPD as a tight PWM driver cell.
4. Place tach conditioning parts together (R_TACH_PU, R_TACH_SERIES, D_TACH_CLAMP).

## Routing priorities
1. Route 12V and GND high-current path to fan connector first.
2. Route PWM sink path short: Q1 collector to J_FAN PWM pin.
3. Route FAN_TACH as a quieter trace back to ESP32 area.
4. Keep tach conditioning close to each other and away from 12V switching currents.

Beginner routing steps:
1. Route 12V/GND first using wider tracks than logic signals.
2. Route PWM path next and keep it direct.
3. Route tach path last and avoid running parallel with 12V for long distance.
4. Press B to repour zones and confirm clean returns.

## Placement done criteria
1. Fan connector and power decoupling are physically coupled.
2. PWM and tach subcircuits are separated enough to reduce coupling.
3. 12V fan path is wide, short, and easy to inspect.

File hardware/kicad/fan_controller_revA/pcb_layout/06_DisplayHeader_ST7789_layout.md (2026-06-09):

# DisplayHeader_ST7789 PCB Layout Guide

Target subsheet: DisplayHeader_ST7789

## Footprints in this cluster
- J_DISP
- R_SCK
- R_MOSI
- R_CS
- R_DC
- R_RST
- C_DISP_VCC
- Q_BL
- R_BL_BASE
- R_BL_PD

## Select this subsheet after schematic update

### Fastest method: right-click → Select → All Footprints in Same Hierarchical Sheet
1. Click any known DisplayHeader_ST7789 footprint — e.g. **J_DISP** — on the canvas.
2. Right-click → **Select** → **All Footprints in Same Hierarchical Sheet**.
3. Confirm J_DISP and any associated resistors/caps are highlighted.
4. Press **M** to move, **R** to rotate so header pins align with display ribbon access, left-click to place.
5. Press **Ctrl+S** to save.

### Fallback: select RefDes list above and move as a cluster.

Beginner click path:
1. Filter Footprints by Sheetname equals DisplayHeader_ST7789.
2. Verify J_DISP and resistor bank parts are selected.
3. Press M to move to intended board edge.
4. Press R until connector orientation matches cable exit direction.

## Placement intent
1. Place J_DISP on board edge with cable exit in mind.
2. Place series resistors as a short row between ESP32 route-in and connector pins.
3. Place C_DISP_VCC close to J_DISP power pins.
4. Place Q_BL + R_BL_BASE + R_BL_PD together near BLK route.

## Routing priorities
1. Route SPI/control traces from ESP32 area to resistor row, then to header.
2. Keep SCK/MOSI/CS/DC/RST traces short and clean.
3. Leave display MISO/SDO unconnected on Rev A.
4. Route BLK sink path with short return to ground reference.

Beginner routing steps:
1. Route from ESP32-side nets into resistor row first.
2. From resistor row, route short final links to J_DISP pins.
3. Keep crossings low; if crossing is needed, add one via and return quickly.
4. Refill zones with B and ensure BLK return has a clear ground path.

## Placement done criteria
1. Connector and resistor bank are aligned for clean breakout.
2. Local VCC bypass sits at the connector power entry.
3. SPI/control traces are not detouring through noisy power zones.

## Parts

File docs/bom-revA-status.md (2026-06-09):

# BOM RevA Status

This file is synchronized to [docs/bom-revA.csv](docs/bom-revA.csv) and reflects the current Rev A sourcing state.

## Summary
- Total BOM line items: 44
- LOCKED: 42
- SOURCED: 0
- PENDING: 0

## Architecture Change Note (2026-05-28)
- Active Rev A programming interface migrated from on-board `ProgrammingUSB` to `ExternalProgrammingHeader`.
- USB bridge-related line items were removed from active BOM.
- Legacy ProgrammingUSB verification data below is retained as archived reference only.

## ProgrammingUSB Interactive Verification (2026-05-21, Archived)
- Live interactive checks on fat.lcsc.com were used as the highest-confidence pass for changed ProgrammingUSB entries.
- Results:
  - C2858418 (CH9102F, QFN-24-EP 4x4): manual browser check later confirmed in-stock quantity.
  - C130723 (NCD0402G1 LED, 0402): product page resolves and is In-Stock.
  - C23186 (5.1k 0603 target): later manual browser check confirmed product page, package 0603, and in-stock quantity.
  - C99198 (10k 0603 target): manual browser check confirmed product page, package 0603, and in-stock quantity.
- Action taken in CSV:
  - Corrected historical wrong mapping: replaced `C2845310` (tactile switch) with `C2858418` for the CH9102F bridge row.
  - Replaced both 10k rows with C99198 and promoted to LOCKED after manual verification.
  - Promoted C2858418 to LOCKED after manual verification.
  - Promoted C23186 to LOCKED after manual verification.
  - Kept C130723 as LOCKED.

## Verification Gate Run (2026-05-21, v1)
- Gate definition source: docs/sourcing-checklist.md (`Verification Gate (v1)`).
- Evidence source preference used: browser-rendered `fat.lcsc.com` snapshots.
- Notes:
  - Direct curl checks now frequently return challenge pages (`Challenge Validation`), so they were used only as a secondary signal.
  - Browser snapshots provided stable `MPN`, `Packaging`, and stock/not-found signals.

### Applied Results
- C2858418 (CH9102F): Identity PASS (`MPN=CH9102F`, `Packaging=QFN-24-EP(4x4)`), Availability PASS (`In-Stock: 4,742`) -> `LOCKED`.
- C969151 (CP2102N-A02-GQFN24R): Identity PASS (`MPN=CP2102N-A02-GQFN24R`, `Packaging=QFN-24-EP(4x4)`), Availability PASS (`In-Stock: 9,595`) -> validated alternate candidate.
- C23186 (5.1k target): Identity PASS (`MPN=0603WAF5101T5E`, `Packaging=0603`), Availability PASS (`In-Stock: 3,559,200`) -> `LOCKED`.
- C99198 (10k target): Identity PASS (`MPN=RC0603JR-0710KL`, `Packaging=0603`), Availability PASS (`In-Stock: 2,616,700`) -> `LOCKED`.
- C130723 (LED): Identity PASS (`MPN=NCD0402G1`, `Packaging=0402`), Availability PASS (`In-Stock: 1,690`) -> `LOCKED`.

## Three-Action Execution Run (2026-05-21)
- Scope requested: execute all three actions (find replacements, verify with gate, patch/recount).
- Discovery source: JLC API (same source family used by kicad-jlcpcb-tools).
- Candidate outcomes:
  - 10k 0603 final selection: `C99198` (manual browser verification confirms in-stock quantity).
  - 5.1k 0603 candidate retained: `C23186` (API response: in-stock, package 0603).
  - CH9102F bridge candidate: `C2858418` (manual browser verification confirms in-stock quantity).
- Browser gate constraints during run:
  - `fat.lcsc.com` returned `Page Not Found` for resistor candidate pages (both short and slug URLs).
  - `www.lcsc.com` product pages repeatedly returned CloudFront `502` in this environment.
- Action taken:
  - Updated both 10k rows in CSV to `C99198` and promoted to `LOCKED` after manual browser verification.
  - Updated `C23186` to `LOCKED` after manual browser verification.
  - Updated `C2858418` to `LOCKED` after manual browser verification.
  - Current counts: `LOCKED 49`, `PENDING 0`.

## Locked Highlights
- Input protection path is locked, including F1:
  - Littelfuse 0466002.NRHF, LCSC C3105
- Fan tach clamp is locked:
  - onsemi MBR0520LT1G, LCSC C23848
- Fan4Wire is lock-clear after fresh root ERC with 0 errors:
  - J_FAN/Q1/R_BASE/R_BPD/R_TACH_PU/R_TACH_SERIES/D_TACH_CLAMP/C_FAN_BULK/C_FAN_HF
- DisplayHeader_ST7789, ExternalProgrammingHeader, and Fan4Wire connector orientation update (2026-06-07):
  - J_DISP switched to right-angle THT header C32713267 (hanxia HX PZ2.54-1x8P WZ)
  - J_PROG switched to right-angle THT header C42453955 (hanxia HX PZ2.54-1x6P WZ-P)
  - J_FAN switched to right-angle THT header C32713263 (hanxia HX PZ2.54-1x4P WZ)
  - Display/program support passives remain unchanged: C2909394, C95177, C307331, C181119, C4190, C25803
- Core power, ESP32 module, display interface, and USB bridge support parts are locked in the CSV.

## Remaining Open Items (PENDING)
- None in the current CSV.

## Notes
- The previous version of this status file contained outdated counts and stale pending sections.
- The CSV remains the source of truth for lock state and LCSC codes.
- Fresh root ERC now passes with 0 errors; remaining ERC items are warnings only.

## Cap Rationalization Review (2026-06-04)

Board layout is getting crowded from electrolytic caps. All caps remain LOCKED and placed as-designed;
this section records which ones are candidates for removal or downsize before finalising placement.
No changes made yet — review during layout completion.

### Candidates to Drop

| Ref | Value | Footprint | Reason |
|-----|---|---|---|
| C12_IN_BULK | 100uF/50V | BD8mm can | C_IN_BULK already buffers VIN_PROTECTED upstream. Drop if trace from C_IN_BULK to U1 input is <4cm and wide (≥0.5mm). |
| C33_IN_BULK | 100uF/50V | BD8mm can | Same argument. Both K7803 and K7812 share VIN_PROTECTED. One upstream bulk cap (C_IN_BULK) is sufficient with tight routing. |
| C_FAN_BULK | 47uF/25V | BD6.3mm can | Optional local bulk at J_FAN. Drop if J_FAN is placed within ~3cm of C12_OUT_BULK with a wide/direct 12V copper path. Keep if fan connector is far from the power stage. |

### Candidates to Downsize

| Ref | Current | Proposed | Reason |
|-----|---|---|---|
| C33_IN_BYP | 10uF/50V X5R 1210 | 1uF/50V X7R 0603 (C15849 — same as C12_IN_BYP) | 1210 is massively oversized for a bypass cap on the module input. 1uF 0603 does the same HF bypass job, saves large board area, and consolidates to an already-stocked part. |

### Keep Unconditionally

- **C_IN_BULK** (100uF/50V can, InputProtection) — first bulk reservoir on VIN_PROTECTED, always required.
- **C12_OUT_BULK** (47uF/25V, BD6.3mm) — required for K7812 stability and fan startup/PWM load transients.
- **C33_OUT_BULK** (100uF/10V, BD6.3mm) — required for K7803 output stability and ESP32 WiFi TX transients.
- **C12_IN_BYP**, **C33_OUT_BYP**, **C12_OUT_BYP**, **C_FAN_HF**, **C_IN_BYP**, **C_DISP_VCC** — all 0402/0603 HF bypass caps, tiny, always keep.
- **C_DEC**, **C_BULK**, **C_EN** — ESP32 decoupling per Espressif reference design, always keep.

### Decision Gate

Before finalising placement: confirm J_FAN distance to C12_OUT_BULK, and measure trace length from C_IN_BULK to U1/U2 input pins on the PCB.
If both routing conditions are met, removing C12_IN_BULK + C33_IN_BULK + replacing C33_IN_BYP saves 2 large BD8mm cans and one 1210 from the board.

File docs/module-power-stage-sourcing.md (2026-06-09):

# Module-Based Power Stage (Option B)

This document is the final implementation reference for Rev A power architecture.

## Scope

- 12V rail from K7812-1000R3 module
- 3.3V rail from EVISUN K7803-1000R3 module
- Both modules fed directly from `VIN_PROTECTED` in parallel
- No discrete buck controllers, no external inductor tuning, no feedback divider design

## Locked Architecture

1. `InputProtection` exports `VIN_PROTECTED`
2. `Power12V` and `Power3V3` both take `VIN_PROTECTED` as input
3. `Power12V` outputs `12V` for the fan power path
4. `Power3V3` outputs `3V3` for ESP32-S3 and logic loads

## Locked Components (from BOM)

| Block | Ref | Part | LCSC | Status |
|---|---|---|---|---|
| InputProtection | D1 | SS36 | C16015 | LOCKED |
| Power12V | U1 | K7812-1000R3 | C5369648 | LOCKED |
| Power12V | C12_IN_BULK | 100uF/50V | C72480 | LOCKED |
| Power12V | C12_IN_BYP | 1uF/50V X7R | C15849 | LOCKED |
| Power12V | C12_OUT_BULK | 47uF/25V | C3029614 | LOCKED |
| Power12V | C12_OUT_BYP | 100nF/50V X7R | C307331 | LOCKED |
| Power3V3 | U2 | EVISUN K7803-1000R3 | C50396472 | LOCKED |
| Power3V3 | C33_IN_BULK | 100uF/50V | C72480 | LOCKED |
| Power3V3 | C33_IN_BYP | 10uF/50V X5R 1210 | C380537 | LOCKED |
| Power3V3 | C33_OUT_BULK | 100uF/10V low-ESR | C2887276 | LOCKED |
| Power3V3 | C33_OUT_BYP | 10uF/16V X5R 0603 | C92487 | LOCKED |

Backup module list (pin-compatible, verified):
- Power12V U1 backup: C969026 (K7812-1000R3, DEXU)
- Power3V3 U2 backup: C5369647 (K7803-1000R3, YLPTEC)

Source of truth: `docs/bom-revA.csv`

## Footprint Guidance

- Use SIP-3 module footprints that match supplier mechanical drawings
- If no exact library footprint exists, create a custom footprint from datasheet dimensions
- Keep symbol and footprint naming consistent with BOM entries

## Layout Rules

1. Place module input/output decoupling caps within 10 mm of corresponding pins
2. Keep VIN and GND returns short and wide
3. Keep high-current fan 12V routing separate from sensitive logic routing
4. Use a continuous ground plane and avoid narrow ground bottlenecks near module returns
5. Keep clear access to power connector and fan connector edges

## Bring-Up Checks

1. Verify `VIN_PROTECTED` under expected input range (19-24V)
2. Verify `12V` regulation under fan load
3. Verify `3V3` during Wi-Fi bursts and display activity
4. Confirm no brownouts on ESP32-S3 during fan startup + Wi-Fi TX
5. Log measured ripple and thermal behavior for Rev A validation notes

## Risk Watch

- K7803 stock depth can vary by vendor lot; prefer C50396472 primary with C5369647 as pre-vetted backup and re-check stock before order freeze
- With SS36 Schottky reverse-polarity protection, 17-18V input operation is not guaranteed. Prefer 19-24V adapters.
- If module substitution is required, re-check pinout, input range, and current rating before BOM update

## References

- `docs/architecture.md`
- `docs/schematic-plan.md`
- `docs/sheet-specs/Power12V.md`
- `docs/sheet-specs/Power3V3.md`
- `docs/bom-revA.csv`
- `docs/bom-revA-status.md`

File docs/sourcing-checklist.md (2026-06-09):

# Sourcing Checklist

Use this checklist before schematic freeze and again before BOM lock.

## What to verify

- Preferred part number
- Preferred LCSC `C` code
- Package footprint match
- Lifecycle status
- Stock at PCBWay-supported sourcing flow
- Stock at LCSC
- Minimum order quantity
- Price trend versus the alternate
- Whether an alternate stays footprint-compatible
- Search query and URL used to find the part (for reproducibility)

## Check sequence

1. Verify the preferred part is active.
2. Verify the preferred package is actually available.
3. Verify the alternate is available only if the preferred part is weak on stock or price.
4. Confirm the part does not force a layout or schematic change.
5. Record the result in the BOM shortlist draft.
6. Record the selected `C` code and at least one alternate `C` code.

## Verification Gate (v1)

Apply this gate before changing any row to `LOCKED`.

1. Identity gate:
	- Product page title resolves (not challenge/not-found).
	- `MPN` matches required part identity.
	- `Packaging` matches the KiCad footprint family and pitch.
2. Availability gate:
	- Page shows `In-Stock` with a positive quantity.
	- `Out of Stock` or `Part not found` is an automatic fail for `LOCKED`.
3. Reproducibility gate:
	- Capture verification date and exact URL used.
	- Keep at least one alternate candidate for critical lines.
4. Conflict handling:
	- If scripted curl output and browser output disagree, trust browser-rendered output.
	- If browser output shows challenge/blocked state, keep row as `PENDING`.

## Row status policy

- `LOCKED`: passes Identity + Availability + Reproducibility gates.
- `PENDING`: any gate fails or cannot be verified in current session.
- `SOURCED`: procurement-confirmed state after supplier order confirmation.

## Decision rule

- Keep the preferred part if it is active, available, and reasonably priced.
- Use the alternate only if it preserves layout risk and does not force a major redesign.
- If both are weak, pause schematic freeze and choose a different family before layout starts.

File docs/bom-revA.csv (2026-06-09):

MPN | Value | Footprint | Qty | References | LCSC_Code | Status | Sheet | Notes
# All resistors are 0603 unless otherwise noted. Capacitors are 0603 unless voltage/capacitance/space requires 0402. See sheet-specs for exceptions.
# K7803/K7812 module sourcing policy: keep one vetted pin-compatible backup per rail in BOM notes and re-check stock at order freeze.
Conn_Screw_5.08mm_1x2 | Screw Terminal 2-pin 5.08mm | TerminalBlock_Altech:Altech_AKZ950_1x02_P5.08mm_45-Degree | 1 | J_PWR | C395939 | LOCKED | InputProtection | Power input 19-24V supported (17-18V not guaranteed with current Schottky reverse-polarity stage); 5.08mm pitch 2-pin screw terminal (THT); alt: C395940
DIODES_SMBJ26A-13-F | SMBJ26A | Diode_SMD:D_SMB | 1 | D_TVS_IN | C135062 | LOCKED | InputProtection | Input transient clamp TVS across VIN_RAW to GND near J_PWR; DIODES SMBJ26A-13-F (SMB) selected
SS36 | SS36 | Diode_SMD:D_SMA | 1 | D1 | C16015 | LOCKED | InputProtection | 60V 3A SMA Schottky for reverse polarity protection at up to 24V input; alt: SS34 (40V | 3A | C8678)
Littelfuse-0466002.NRHF | 2A/63V | Fuse:Fuse_1206_3216Metric | 1 | F1 | C3105 | LOCKED | InputProtection | Pragmatic Rev A policy: 2A 1206 fuse (fast-acting acceptable); selected Littelfuse 0466002.NRHF
Cap_100n_50V_X7R_0402 | 100nF/50V | Capacitor_SMD:C_0402_1005Metric | 1 | C_IN_BYP | C307331 | LOCKED | InputProtection | 100nF X7R 0402
Cap_100u_50V_Input | 100uF/50V | Capacitor_SMD:C_Radial_SMD_8.0x10.5 | 1 | C_IN_BULK | C72480 | LOCKED | InputProtection | Bulk input reservoir across VIN_PROTECTED to GND near connector/diode output; polarized (+ to VIN_PROTECTED | - to GND)
K7812-1000R3 | K7812-1000 | Module:SIP_11.6x7.6mm_3pin | 1 | U1 | C5369648 | LOCKED | Power12V | K7812-1000R3 12V 1A SIP-3 DC/DC module (YLPTEC); verified in stock; backup: C969026 (DEXU K7812-1000R3)
Cap_100u_50V | 100uF/50V | Capacitor_SMD:C_Radial_SMD_8.0x10.5 | 1 | C12_IN_BULK | C72480 | LOCKED | Power12V | Input bulk decap for K7812; CAP-REVIEW: candidate to drop — C_IN_BULK (InputProtection) already buffers VIN_PROTECTED; only retain if trace from C_IN_BULK to U1 input pin is >4cm or narrow; see cap-rationalization note in bom-revA-status.md
Cap_1u_50V_X7R_0603 | 1uF/50V X7R | Capacitor_SMD:C_0603_1608Metric | 1 | C12_IN_BYP | C15849 | LOCKED | Power12V | HF input bypass for K7812 on VIN_PROTECTED rail (19-24V supported)
Cap_47u_25V_12VOUT | 47uF/25V | Capacitor_SMD:C_Radial_SMD_6.3x7.7 | 1 | C12_OUT_BULK | C3029614 | LOCKED | Power12V | Output bulk decap at K7812 VOUT to handle fan startup and PWM load transients
Cap_100n_50V_X7R_0402_12VOUT | 100nF/50V X7R | Capacitor_SMD:C_0402_1005Metric | 1 | C12_OUT_BYP | C307331 | LOCKED | Power12V | Output HF bypass at K7812 VOUT for switching noise suppression
EVISUN-K7803-1000R3 | K7803-1000 | Module:SIP_11.6x7.6mm_3pin | 1 | U2 | C50396472 | LOCKED | Power3V3 | K7803-1000R3 3.3V 1A SIP-3 DC/DC module (EVISUN); verified in stock; backup: C5369647 (YLPTEC K7803-1000R3)
Cap_100u_50V | 100uF/50V | Capacitor_SMD:C_Radial_SMD_8.0x10.5 | 1 | C33_IN_BULK | C72480 | LOCKED | Power3V3 | Input bulk decap for K7803; same stocked 100uF/50V part used on VIN input and Power12V; CAP-REVIEW: candidate to drop — same argument as C12_IN_BULK; both modules share VIN_PROTECTED and C_IN_BULK provides upstream bulk; drop if routing is tight; see cap-rationalization note in bom-revA-status.md
Cap_10u_50V_X5R_1210 | 10uF/50V X5R | Capacitor_SMD:C_1210_3225Metric | 1 | C33_IN_BYP | C380537 | LOCKED | Power3V3 | HF input bypass for K7803 on VIN_PROTECTED rail; Samsung CL32A106KBJNNNE; CAP-REVIEW: 1210 footprint is oversized for a bypass cap — candidate to replace with 1uF 0603 (same as C12_IN_BYP | C15849 | already in BOM); saves significant board area with no functional loss; see cap-rationalization note in bom-revA-status.md
Cap_100u_10V_low_ESR | 100uF/10V low-ESR | Capacitor_SMD:C_Radial_SMD_6.3x7.7 | 1 | C33_OUT_BULK | C2887276 | LOCKED | Power3V3 | Output bulk cap for K7803
Cap_10u_16V_X5R_0603 | 10uF/16V X5R | Capacitor_SMD:C_0603_1608Metric | 1 | C33_OUT_BYP | C92487 | LOCKED | Power3V3 | HF output bypass for K7803; Samsung CL10A106MO8NQNC
ESP32-S3-WROOM-1-N16R8 | ESP32-S3-WROOM-1-N16R8 | Module:ESP32-S3-WROOM-1 | 1 | U3 | C2913202 | LOCKED | ESP32S3Core | Espressif ESP32-S3-WROOM-1-N16R8; alt: C2913201 (N8R8)
Cap_100n_10V_X7R_0402 | 100nF/10V X7R | Capacitor_SMD:C_0402_1005Metric | 1 | C_DEC | C307331 | LOCKED | ESP32S3Core | 100nF/50V X7R 0402; alt: C1525
Cap_22u_16V_X5R_1206 | 22uF/16V X5R | Capacitor_SMD:C_1206_3216Metric | 1 | C_BULK | C90146 | LOCKED | ESP32S3Core | 22uF/16V X5R 1206 bulk cap for ESP32 local burst current support; Samsung CL31A226KOHNNNE
Res_10k_0603 | 10kOhm | Resistor_SMD:R_0603_1608Metric | 2 | R_EN R_BOOT | C99198 | LOCKED | ESP32S3Core | 10k 0603 pull-ups for EN and GPIO0_BOOT; manual browser verification confirmed MPN RC0603JR-0710KL | package 0603 | and in-stock quantity
CL10B105KB8NNNC | 1uF/50V X7R | Capacitor_SMD:C_0603_1608Metric | 1 | C_EN | C15849 | LOCKED | ESP32S3Core | EN reset RC capacitor per Espressif recommendation (typical R=10k and C=1uF); tune only if rail ramp behavior requires it
TL3342F160QG | Momentary tactile switch | Button_Switch_SMD:SW_SPST_TL3342 | 2 | SW_RESET SW_BOOT | C2886898 | LOCKED | ESP32S3Core | Manual reset and BOOT buttons; TL3342-compatible SMD tactile
HX PZ2.54-1x4P WZ | 4-pin fan header | Connector_PinHeader_2.54mm:PinHeader_1x04_P2.54mm_Horizontal | 1 | J_FAN | C32713263 | LOCKED | Fan4Wire | 1x4 right-angle male header for fan cable breakout; hanxia HX PZ2.54-1x4P WZ | 2.54mm single-row TH right-angle (Intel 4-pin PWM net order: 1-GND | 2-12V | 3-TACH | 4-PWM)
MMBT3904_Q1 | NPN SOT-23 | Package_TO_SOT_SMD:SOT-23 | 1 | Q1 | C181119 | LOCKED | Fan4Wire | PWM open-collector sink; alt C111113 C916374
Res_2k2_0603 | 2.2kOhm | Resistor_SMD:R_0603_1608Metric | 1 | R_BASE | C4190 | LOCKED | Fan4Wire | Q1 base current limit
Res_100k_0603 | 100kOhm | Resistor_SMD:R_0603_1608Metric | 1 | R_BPD | C25803 | LOCKED | Fan4Wire | Q1 base pull-down; alt: C21198
Res_10k_0603_fan | 10kOhm | Resistor_SMD:R_0603_1608Metric | 1 | R_TACH_PU | C98220 | LOCKED | Fan4Wire | Tach pull-up to 3V3
Res_1k_0603_fan | 1kOhm | Resistor_SMD:R_0603_1608Metric | 1 | R_TACH_SERIES | C22548 | LOCKED | Fan4Wire | Tach GPIO series protection
onsemi-MBR0520LT1G | MBR0520LT1G | Diode_SMD:D_SOD-123 | 1 | D_TACH_CLAMP | C23848 | LOCKED | Fan4Wire | Tach over-voltage clamp; cathode to 3V3 and anode to FAN_TACH (MCU side)
Cap_47u_25V_FAN | 47uF/25V | Capacitor_SMD:C_Radial_SMD_6.3x7.7 | 1 | C_FAN_BULK | C3029614 | LOCKED | Fan4Wire | Local 12V bulk at fan connector; Lelon VUA470M1ETR-0607 (SMD | D6.3xL7.7mm); CAP-REVIEW: optional — can drop if J_FAN is placed within ~3cm of C12_OUT_BULK with wide/direct 12V copper between them; keep if fan connector is far from power stage; see cap-rationalization note in bom-revA-status.md
Cap_100n_25V_X7R_0402 | 100nF/25V | Capacitor_SMD:C_0402_1005Metric | 1 | C_FAN_HF | C307331 | LOCKED | Fan4Wire | HF bypass at J_FAN 12V; same part as C_IN_BYP
Conn_PinHeader_2.54mm_1x8 | 8-pin display header | Connector_PinHeader_2.54mm:PinHeader_1x08_P2.54mm_Horizontal | 1 | J_DISP | C32713267 | LOCKED | DisplayHeader_ST7789 | 1x8 right-angle male header for ST7789 cable breakout; hanxia HX PZ2.54-1x8P WZ | 2.54mm single-row TH right-angle
Res_33R_0603 | 33Ohm | Resistor_SMD:R_0603_1608Metric | 5 | R_SCK R_MOSI R_CS R_DC R_RST | C2909394 | LOCKED | DisplayHeader_ST7789 | SPI signal damping; FOJAN FRC0603F33R0TS | 33R 0603 thick-film | stocked
Res_0R_DNP_0603 | 0Ohm DNP | Resistor_SMD:R_0603_1608Metric | 1 | R_MISO | C95177 | LOCKED | DisplayHeader_ST7789 | MISO DNP unless needed; YAGEO RC0603JR-070RL | 0R 0603 stocked optional link
Cap_100n_10V_0402_disp | 100nF/10V | Capacitor_SMD:C_0402_1005Metric | 1 | C_DISP_VCC | C307331 | LOCKED | DisplayHeader_ST7789 | Bypass at header VCC; same part as C_IN_BYP
MMBT3904_dispbl | NPN SOT-23 | Package_TO_SOT_SMD:SOT-23 | 1 | Q_BL | C181119 | LOCKED | DisplayHeader_ST7789 | Display BL open-collector sink transistor; same part as Q1 and auto-reset NPNs
Res_2k2_0603_dispbl | 2.2kOhm | Resistor_SMD:R_0603_1608Metric | 1 | R_BL_BASE | C4190 | LOCKED | DisplayHeader_ST7789 | Base current limit for Q_BL open-collector stage
Res_100k_0603_dispbl | 100kOhm | Resistor_SMD:R_0603_1608Metric | 1 | R_BL_PD | C25803 | LOCKED | DisplayHeader_ST7789 | Base pull-down for Q_BL open-collector stage
Conn_PinHeader_2.54mm_1x6 | 6-pin programming header | Connector_PinHeader_2.54mm:PinHeader_1x06_P2.54mm_Horizontal | 1 | J_PROG | C42453955 | LOCKED | ExternalProgrammingHeader | External right-angle programming header (GND 3V3 UART_TX UART_RX EN_RESET GPIO0_BOOT) for external downloader cable; hanxia HX PZ2.54-1x6P WZ-P
PZ2.54-2X5P-H25 | 2x5 expansion header | Connector_PinHeader_2.54mm:PinHeader_2x05_P2.54mm_Vertical | 1 | J_EXP | C42431818 | LOCKED | OptionalExpansionHeader | 2x5 2.54mm GPIO expansion
Res_33R_0603_exp | 33Ohm | Resistor_SMD:R_0603_1608Metric | 8 | R_EXP1 R_EXP2 R_EXP3 R_EXP4 R_EXP5 R_EXP6 R_EXP7 R_EXP8 | C2909394 | LOCKED | OptionalExpansionHeader | Series protection on each GPIO; same 33R 0603 used on display lines
0805L050WR | Polyfuse 500mA | Fuse:Fuse_0805_2012Metric | 1 | F_EXP | C207022 | LOCKED | OptionalExpansionHeader | 3V3 expansion protection; Littelfuse 6V 500mA resettable PTC 0805

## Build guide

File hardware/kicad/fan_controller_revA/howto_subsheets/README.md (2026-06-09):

# Subsheet How-To Index

Use one file per schematic sheet while capturing symbols and wiring.

These guides are written for a fully manual KiCad workflow. You do not need an AI-generated starting schematic. If a sheet does not exist yet, create it from the root sheet first, then follow the matching guide.

## Files
- 01_InputProtection.md
- 02_Power12V.md
- 03_Power3V3.md
- 04_ESP32S3Core.md
- 05_Fan4Wire.md
- 06_DisplayHeader_ST7789.md
- 07_ExternalProgrammingHeader.md
- 07_ProgrammingUSB.md
- 08_TestPoints.md
- 10_OptionalExpansionHeader.md
- 11_RootIntegration_CrossSheet.md
- 12_EndToEnd_ProjectFlow.md

## Recommended workflow
1. Open the root sheet in KiCad.
2. Create the next child sheet manually if it does not exist yet.
3. Name the sheet and file exactly as the guide expects.
4. Open that child sheet and follow the matching how-to file step by step.
5. Run ERC after each subsheet.
6. Return to root sheet and sync sheet pins.
7. Run full-project ERC before footprint assignment.

## Shortcut hints
1. `A` adds a symbol.
2. `W` starts a wire.
3. `L` adds a net label.
4. `P` adds a power symbol.
5. `R` rotates the selected item.
6. `M` moves the selected item.
7. `G` drags while keeping wires attached.
8. `E` opens item properties.
9. `Del` deletes the selected item.
10. `Ctrl+S` saves.
11. `Esc` cancels the current tool.

If a shortcut differs in your KiCad version, use the toolbar or context-menu equivalent and keep the workflow moving.

Note:
- `07_ProgrammingUSB.md` is archived reference content only.
- `07_ExternalProgrammingHeader.md` is the active Rev A programming-interface guide.

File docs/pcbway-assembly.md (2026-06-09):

# PCBWay Assembly Notes

## Assembly strategy

- The design should be buildable as PCBWay PCBA without user soldering
- Favor SMT parts for the core circuitry
- Use through-hole connectors only when PCBWay can assemble them as part of the order
- Avoid any part that depends on the end user hand-soldering a critical connection

## Manufacturing constraints

- Keep the PCB outline under 99x99 mm
- Keep connector placement compatible with automated assembly and inspection
- Provide a clean BOM with sourceable MPNs and clear alternates

## Review gates

- Verify every required part can be sourced for PCBWay assembly
- Verify connector footprints and orientations before locking the board
- Verify the final outline stays under the target size after keep-outs are applied

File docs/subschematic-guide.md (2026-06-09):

# Sub-Schematic Recommendation — Rev A

What to put on each sheet. Start with sheets that have no dependencies, then work towards the ESP32 sheet.

This guide is for manual schematic capture. Treat each block below as the target state for a blank child sheet, not as a patch against previously generated content.

Manual setup reminder:
1. Start on the root sheet.
2. Create the child sheet symbol and give it the expected name.
3. Open the child sheet file.
4. Place symbols, wires, and labels from the matching block below.
5. Return to root only after the child sheet is internally coherent.

---

## Capture Order (dependency-safe)

```
1. InputProtection   — no upstream deps
2. Power12V          — needs VIN_PROTECTED from sheet 1
3. Power3V3          — needs VIN_PROTECTED from sheet 1
4. Fan4Wire          — needs 12V, 3V3, FAN_PWM/TACH (define nets, wire later)
5. DisplayHeader     — needs 3V3, SPI nets
6. ExternalProgrammingHeader — needs 3V3, UART_TX/RX, EN_RESET, GPIO0_BOOT
7. OptionalExpansion — needs 3V3, GPIO nets
8. TestPoints        — pure TP pads, no active nets needed
9. ESP32S3Core       — place last; connects all signal nets together
```

Shortcut hints:
- `A` add symbol
- `W` wire
- `L` net label
- `P` power symbol
- `G` drag connected items
- `E` edit properties
- `Esc` cancel current command

---

## Sheet Contents

### InputProtection
```
J_PWR (2-pin screw terminal 5.08mm pitch)  → VIN_RAW
D_TVS_IN (SMBJ26A, SMB) from VIN_RAW to GND
D1 (SS36 SMA)  ←  VIN_RAW
F1 (2A fuse 1206)
C_IN_BYP (100nF 0402) across output
→ exports: VIN_PROTECTED, GND
```

### Power12V
```
U1 (K7812 module, SIP-3)  ←  VIN_PROTECTED
C12_IN_BULK (100uF/50V radial) — input bulk
C12_IN_BYP (1uF/50V 0603)      — input bypass
→ exports: 12V
(no feedback network, no inductor, no diode — module only)
```

### Power3V3
```
U2 (K7803 module, SIP-3)  ←  VIN_PROTECTED (parallel input, not from 12V)
C33_IN_BULK (100uF/50V radial) — input bulk
C33_IN_BYP (10uF/50V 1210)     — input bypass
C33_OUT_BULK (100uF/10V radial) — output bulk
C33_OUT_BYP (10uF/16V 0603)     — output bypass
→ exports: 3V3
```

### Fan4Wire
```
J_FAN (1x4 2.54mm)
  pin 1 → GND
  pin 2 → 12V  ← also: C_FAN_BULK (47uF) + C_FAN_HF (100nF) to GND
    pin 3 → tach conditioning: [R_TACH_PU 10k to 3V3] → [R_TACH_SERIES 1k] → FAN_TACH
      and [D_TACH_CLAMP Schottky] from FAN_TACH to 3V3 (cathode 3V3, anode FAN_TACH)
  pin 4 → Q1 collector (FAN_PWM_OC)

Q1 (MMBT3904 SOT-23)
  base  ← [R_BASE 2.2k] ← FAN_PWM
  base  → [R_BPD 100k]  → GND
  emitter → GND
  collector → J_FAN pin 4

← imports: 12V, 3V3, FAN_PWM
→ exports: FAN_TACH
```

### DisplayHeader_ST7789
```
J_DISP (1x8 2.54mm right-angle header)
  pin 1 → GND
  pin 2 → 3V3 ← [C_DISP_VCC 100nF] to GND
  pin 3 → SPI_SCK   ← [R_SCK 33R] ← GPIO6
  pin 4 → SPI_MOSI  ← [R_MOSI 33R]← GPIO7
  pin 5 → DISP_RST  ← [R_RST 33R] ← GPIO16
  pin 6 → DISP_DC   ← [R_DC 33R]  ← GPIO9
  pin 7 → DISP_CS   ← [R_CS 33R]  ← GPIO10

Q_BL (MMBT3904 SOT-23)
  base  ← [R_BL_BASE 2.2k] ← DISP_BL (GPIO40 PWM)
  base  → [R_BL_PD 100k]   → GND
  emitter → GND
  collector → J_DISP pin 8 (BLK)

Rev A policy:
  J_DISP MISO/SDO (if present on module) is left NC (not connected)

← imports: 3V3, GPIO6/7/8/9/10/16/40 (via net names)
```

### ExternalProgrammingHeader
```
J_PROG (1x6 2.54mm right-angle header)
  pin 1 → GND
  pin 2 → 3V3
  pin 3 → UART_TX (ESP32 GPIO43)
  pin 4 → UART_RX (ESP32 GPIO44)
  pin 5 → EN_RESET
  pin 6 → GPIO0_BOOT

External programmer wiring:
  adapter TX → UART_RX
  adapter RX ← UART_TX
  adapter reset control → EN_RESET (optional auto-program)
  adapter boot control  → GPIO0_BOOT (optional auto-program)

← imports: 3V3, UART_TX, UART_RX, EN_RESET, GPIO0_BOOT
```

### OptionalExpansionHeader  *(DNP entire sheet if not needed)*
```
J_EXP (2x5 2.54mm)
  3V3 pin → [F_EXP polyfuse 500mA] → 3V3
  GND pin → GND
  GPIO pins → [R_EXP1–8 33R each] → GPIO17/18/19/20/21/38/39/41

← imports: 3V3, free GPIOs
```

### TestPoints
```
TP1  VIN_PROTECTED
TP2  12V
TP3  3V3
TP4  GND
TP5  FAN_PWM
TP6  FAN_TACH
TP7  UART_TX
TP8  UART_RX
TP9  EN_RESET
TP10 GPIO0_BOOT

(TP pads only — no purchased components)
```

### ESP32S3Core  *(capture last — all nets must already exist)*
```
U3 (ESP32-S3-WROOM-1-N16R8)
  VDD → 3V3
  GND → GND (pins 1, 40, 41, EP)
  GPIO4  ← FAN_TACH
  GPIO5  → FAN_PWM
  GPIO6  → SPI_SCK
  GPIO7  → SPI_MOSI
  GPIO9  → DISP_DC
  GPIO10 → DISP_CS
  GPIO16 → DISP_RST
  GPIO40 → DISP_BL
  GPIO43 → UART_TX
  GPIO44 ← UART_RX
  GPIO17–42 (selected) → expansion nets
  EN     ← EN_RESET
  GPIO0  ← GPIO0_BOOT

Decoupling on this sheet:
  C_BULK (10uF 0603) at VDD pin
  C_DEC (100nF 0402) at VDD pin
  R_EN (10k) EN to 3V3; C_EN (1uF 0603) EN to GND
  R_BOOT (10k) GPIO0 to 3V3
  SW_RESET button EN to GND
  SW_BOOT button GPIO0 to GND
```

### Future Revision Note
```
Onboard rail telemetry is intentionally deferred from Rev A.
If bring-up later shows a real need, add a dedicated telemetry sheet in a future revision instead of reserving GPIOs and BOM lines now.
```

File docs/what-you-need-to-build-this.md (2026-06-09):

# What You Need to Build This

This section lists all the essential items required to assemble, program, and use the ESP32 Fan Controller Rev A.

## Required Parts (not included in PCB assembly)

- **Power Supply:** 19-24V DC, 2A+ recommended (laptop brick or equivalent, 5.5x2.1mm or screw terminal). 17-18V operation is not guaranteed with the current Schottky reverse-polarity stage.
- **4-Pin PWM Fan:** Standard PC 12V 4-wire PWM fan (Intel pinout)
- **Display:** ST7789 SPI display module (1.3", 1.54", or 2.0"; 3.3V logic)
- **USB-UART Adapter:** 3.3V logic adapter (or ESP32 downloader) with TX/RX/GND and optional EN/BOOT control lines
- **Dupont Cables/Crimps:** Male/female Dupont leads for display/programming header extension and bring-up wiring

## Power Requirement for Programming

- **Important:** Programming/logging is via the external 1x6 programming header (`J_PROG`) and an external USB-UART adapter.
- The board must be powered from the external **19-24V supported input** during programming and serial logging.
- External programmer cable alone will not power the board logic rail in the current Rev A design unless you intentionally inject 3V3.

## Optional/Recommended

- **Screwdriver:** For terminal block
- **Jumper wires:** For expansion header or test points
- **Breadboard/Prototyping tools:** For experimenting with expansion GPIOs
- **Case or standoffs:** For mounting the assembled board

## Assembly/Bringup Checklist

- Confirm all required parts are present
- Connect power supply to screw terminal
- Connect fan to 4-pin header (verify pinout: 1-GND, 2-12V, 3-TACH, 4-PWM)
- Connect display to SPI header (verify pinout per display module)
- Connect external USB-UART adapter to `J_PROG` (TX/RX crossed, common GND, optional EN/BOOT)
- (Optional) Connect expansion header or telemetry as needed

See the BOM and sheet-specs for detailed part numbers and pinouts.

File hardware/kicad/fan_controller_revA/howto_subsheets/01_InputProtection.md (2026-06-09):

# InputProtection How-To (Beginner Version)

Target sheet: InputProtection

## What this sheet does
This sheet takes raw DC input from the screw terminal, protects it, and exports a cleaner rail for the rest of the board.

Think of it as:
- Input in: VIN_RAW + GND from J_PWR
- Protection: fuse + reverse-polarity diode + TVS
- Output out: VIN_PROTECTED + GND

## Parts to place
| RefDes | Part | LCSC | Why it is here |
|---|---|---|---|
| J_PWR | Conn_Screw_5.08mm_1x2 | C395939 | External power entry connector |
| F1 | Littelfuse-0466002.NRHF | C3105 | Input overcurrent protection |
| D1 | SS36 | C16015 | Reverse-polarity protection path |
| D_TVS_IN | DIODES_SMBJ26A-13-F | C135062 | Surge clamp on input rail |
| C_IN_BYP | 100nF 50V X7R 0402 | C307331 | High-frequency input bypass |
| C_IN_BULK | 100uF 50V input bulk cap | C72480 | Bulk reservoir on protected input |

## Before wiring
1. Open the root schematic.
2. If sheet InputProtection does not exist, create a hierarchical sheet named InputProtection and set its file to InputProtection.
3. Open the InputProtection subsheet.
4. Place J_PWR, F1, D1, D_TVS_IN, C_IN_BYP, and C_IN_BULK.

## Pin-level wiring (connect this to that)
Use the Wire tool and connect exactly these nets:

1. Input chain
- J_PWR VIN pin -> F1 input
- F1 output -> D1 anode
- D1 cathode -> VIN_PROTECTED net

2. Input return
- J_PWR GND pin -> GND net

3. TVS protection
- D_TVS_IN between VIN_RAW side and GND
- TVS cathode -> input side net before protection
- TVS anode -> GND

4. Bypass and bulk capacitors
- C_IN_BYP between input-side rail and GND
- C_IN_BULK between VIN_PROTECTED and GND
- C_IN_BULK positive pin -> VIN_PROTECTED
- C_IN_BULK negative pin -> GND

5. Required labels
- Add VIN_RAW label at connector side
- Add VIN_PROTECTED label after fuse/diode protection
- Add GND symbols for return net
- Add hierarchical labels VIN_RAW and VIN_PROTECTED

## Placement guidance (simple and practical)
1. Put F1 and D1 close to J_PWR to keep the unprotected path short.
2. Put D_TVS_IN physically close to the connector entry.
3. Put C_IN_BYP close to the connector and protection input side.
4. Put C_IN_BULK close to the VIN_PROTECTED output side.
5. Keep high-current input traces short and wide where practical.

## Architecture rules you must keep
1. VIN_RAW is only at the connector side, before protection.
2. VIN_PROTECTED is only after protection and feeds the power-conversion sheets.
3. Do not bypass the fuse or reverse-polarity stage.
4. Keep GND as a single shared return net.

## Root-sheet hookup check
In the root sheet, make sure:
1. VIN_RAW enters InputProtection from the external input path.
2. VIN_PROTECTED exits InputProtection to Power12V and Power3V3.
3. GND is shared consistently with the rest of the project.

## Common mistakes to avoid
1. Reversing C_IN_BULK polarity.
2. Placing VIN_RAW label after the protection chain.
3. Forgetting to connect TVS return to GND.
4. Leaving the fuse out of series with the input path.

## Final checks (2-minute checklist)
1. J_PWR input path goes through F1 and D1 before VIN_PROTECTED.
2. TVS is connected across input rail to GND.
3. C_IN_BYP and C_IN_BULK are connected to the correct rails.
4. VIN_RAW and VIN_PROTECTED labels are present and in the right locations.
5. ERC has no real wiring errors for this sheet.

## Exit criteria
- VIN_PROTECTED is generated from a protected input path.
- Input protection parts are fully wired and labeled.
- Sheet is ready to feed Power12V and Power3V3.

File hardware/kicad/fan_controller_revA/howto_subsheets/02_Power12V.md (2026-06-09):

# Power12V How-To (Beginner Version)

Target sheet: Power12V

## What this sheet does
This sheet turns VIN_PROTECTED (from InputProtection) into a clean 12V rail using one integrated regulator module (K7812).

Think of it as:
- Input in: VIN_PROTECTED + GND
- Regulated output out: 12V + GND

## Parts to place
| RefDes | Part | LCSC | Why it is here |
|---|---|---|---|
| U1 | K7812-1000R3 | C5369648 | Makes 12V from VIN_PROTECTED |
| C12_IN_BULK | 100uF 50V electrolytic | C72480 | Bulk input smoothing |
| C12_IN_BYP | 1uF 50V X7R 0603 | C15849 | Input bypass |
| C12_OUT_BULK | 47uF 25V electrolytic | C3029614 | Output bulk for fan startup and PWM load transients |
| C12_OUT_BYP | 100nF 50V X7R 0402 | C307331 | Output bypass at regulator VOUT |

## Before wiring
1. Open the root schematic.
2. If sheet Power12V does not exist, create a hierarchical sheet named Power12V and set its file to Power12V.
3. Open the Power12V subsheet.
4. Place U1, C12_IN_BULK, C12_IN_BYP, C12_OUT_BULK, and C12_OUT_BYP.

## Pin-level wiring (connect this to that)
Use the Wire tool and connect exactly these nets:

1. VIN_PROTECTED net
- U1 VIN pin -> VIN_PROTECTED label
- C12_IN_BULK positive pin -> VIN_PROTECTED
- C12_IN_BYP pin 1 -> VIN_PROTECTED

2. GND net
- U1 GND pin -> GND label
- C12_IN_BULK negative pin -> GND
- C12_IN_BYP pin 2 -> GND

3. 12V output net
- U1 VOUT pin -> 12V label
- C12_OUT_BULK positive pin -> 12V
- C12_OUT_BYP pin 1 -> 12V

4. Output return to GND
- C12_OUT_BULK negative pin -> GND
- C12_OUT_BYP pin 2 -> GND

Important polarity note:
- Electrolytics must be oriented correctly.
- C12_IN_BULK: + to VIN_PROTECTED, - to GND.

## Placement guidance (simple and practical)
1. Put C12_IN_BULK and C12_IN_BYP physically close to U1 VIN and GND pins.
2. Put C12_OUT_BULK and C12_OUT_BYP physically close to U1 VOUT and GND pins.
3. Keep the VIN_PROTECTED and GND wires short between U1 and both input capacitors.
4. Keep output-cap wiring short from U1 VOUT to C12_OUT_BULK/C12_OUT_BYP and then to GND.
5. Keep 12V trace short from U1 VOUT to the 12V label.
6. Use the same GND net everywhere in this sheet.

## Architecture rules you must keep
1. Feed U1 directly from VIN_PROTECTED.
2. Do not cascade this stage from another rail.
3. Do not add inductor, catch diode, or feedback divider.
4. This design uses integrated K78xx modules only.

## Root-sheet hookup check
In the root sheet, make sure:
1. VIN_PROTECTED enters this Power12V sheet.
2. 12V leaves this sheet toward the fan stage.
3. GND is shared consistently across sheets.

## Common mistakes to avoid
1. Reversing C12_IN_BULK polarity.
2. Forgetting to wire C12_IN_BYP to both VIN_PROTECTED and GND.
3. Naming output net something else (must be exactly 12V).
4. Mixing up U1 pin names; always follow the K7812 symbol pin names VIN, GND, VOUT.

## Final checks (2-minute checklist)
1. ERC runs with no real wiring errors.
2. U1 VIN is on VIN_PROTECTED, not on raw VIN.
3. U1 VOUT goes to 12V and the net name is exactly 12V.
4. U1 GND and all capacitor returns are on GND.
5. C12_IN_BULK polarity is correct.

## Exit criteria
- 12V net is generated and exported.
- Only module-based architecture is used (no discrete buck power stage).
- Sheet passes ERC after intentional warnings are reviewed.

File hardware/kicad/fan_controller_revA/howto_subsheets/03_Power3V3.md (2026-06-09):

# Power3V3 How-To (Beginner Version)

Target sheet: Power3V3

## What this sheet does
This sheet turns VIN_PROTECTED (from InputProtection) into a clean 3V3 rail using one integrated regulator module (K7803).

Use the project-local KiCad symbol `lcsc_imported:K7803-1000R3_C50396472` for U2.

Think of it as:
- Input in: VIN_PROTECTED + GND
- Regulated output out: 3V3 + GND

## Parts to place
| RefDes | Part | LCSC | Why it is here |
|---|---|---|---|
| U2 | EVISUN-K7803-1000R3 | C50396472 | Makes 3.3V from VIN_PROTECTED |
| C33_IN_BULK | 100uF 50V electrolytic | C72480 | Bulk smoothing on module input |
| C33_IN_BYP | 10uF 50V X5R ceramic, 1210 | C380537 | Input bypass |
| C33_OUT_BULK | 100uF 10V electrolytic | C2887276 | Bulk output reserve for load spikes |
| C33_OUT_BYP | 10uF 16V X5R ceramic, 0603 | C92487 | Output bypass |

## Before wiring
1. Open the root schematic.
2. If Power3V3 sheet does not exist, create hierarchical sheet Power3V3 and set file Power3V3.
3. Open the Power3V3 subsheet.
4. Place U2, C33_IN_BULK, C33_IN_BYP, C33_OUT_BULK, and C33_OUT_BYP.

## Pin-level wiring (connect this to that)
Use the Wire tool and connect exactly these nets:

1. VIN_PROTECTED net (input side)
- U2 VIN pin -> VIN_PROTECTED label
- C33_IN_BULK positive pin -> VIN_PROTECTED
- C33_IN_BYP pin 1 -> VIN_PROTECTED

2. GND net (shared return)
- U2 GND pin -> GND label
- C33_IN_BULK negative pin -> GND
- C33_IN_BYP pin 2 -> GND
- C33_OUT_BULK negative pin -> GND
- C33_OUT_BYP pin 2 -> GND

3. 3V3 net (output side)
- U2 VOUT pin -> 3V3 label
- C33_OUT_BULK positive pin -> 3V3
- C33_OUT_BYP pin 1 -> 3V3

Important polarity note:
- Electrolytics must be oriented correctly.
- C33_IN_BULK: + to VIN_PROTECTED, - to GND.
- C33_OUT_BULK: + to 3V3, - to GND.

## Placement guidance (simple and practical)
1. Keep C33_IN_BULK and C33_IN_BYP close to U2 VIN/GND pins.
2. Keep C33_OUT_BULK and C33_OUT_BYP close to U2 VOUT/GND pins.
3. Keep all capacitor-to-module wires short.
4. Use the same GND net everywhere in this sheet.

## Architecture rules you must keep
1. Feed U2 directly from VIN_PROTECTED.
2. Do not feed U2 from 12V.
3. Do not add inductor, catch diode, or feedback resistors.
4. This design uses integrated K78xx modules only.

## Root-sheet hookup check
In the root sheet, confirm:
1. VIN_PROTECTED enters Power3V3 sheet.
2. 3V3 leaves this sheet to ESP32S3Core and other consumers.
3. GND is common and consistent across all sheets.

## Common mistakes to avoid
1. Reversing electrolyte capacitor polarity.
2. Forgetting to connect output capacitors to 3V3.
3. Writing net name 3.3V or V3P3 instead of 3V3.
4. Accidentally using 12V as input to U2.

## Final checks (2-minute checklist)
1. ERC has no real wiring errors.
2. U2 VIN is on VIN_PROTECTED.
3. U2 VOUT, C33_OUT_BULK+, and C33_OUT_BYP pin 1 are on 3V3 and the net name is exactly 3V3.
4. All capacitor negative sides are on GND.
5. No discrete buck converter parts exist in this sheet.

## Exit criteria
- 3V3 net is exported and cleanly labeled.
- Sheet follows the module-based Rev A architecture.
- Sheet passes ERC after intentional warnings are reviewed.

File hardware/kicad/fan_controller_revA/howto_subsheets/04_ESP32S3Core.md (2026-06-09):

# ESP32S3Core How-To (Beginner Version)

Target sheet: ESP32S3Core

## What this sheet does
This sheet places the ESP32-S3 module and gives it the minimum support parts it needs to boot, reset, talk to USB programming, control the fan, and drive the display.

Think of it as:
- Power in: 3V3 + GND
- Control core: ESP32-S3 module + decoupling + boot/reset parts
- Signals out: FAN_PWM, FAN_TACH, SPI_SCK, SPI_MOSI, DISP_CS, DISP_DC, DISP_RST, DISP_BL, UART_TX, UART_RX, EN_RESET, GPIO0_BOOT

Important capture rule:
- Build this sheet after the power sheets and after you already know the net names you want to export.

## Parts to place
| RefDes | Part | LCSC | Why it is here |
|---|---|---|---|
| U3 | ESP32-S3-WROOM-1-N16R8 | C2913202 | Main MCU and wireless module |
| C_DEC | 100nF 10V X7R 0402 | C307331 | Local high-frequency decoupling on the 3V3 rail |
| C_BULK | 22uF 16V X5R 1206 | C90146 | Local bulk decoupling for ESP32 current bursts |
| R_EN | 10k 0603 | C99198 | Pulls EN high for normal operation |
| R_BOOT | 10k 0603 | C99198 | Pulls GPIO0 high for normal boot |
| R_JTAG | 10k 0603 | C99198 | Pulls GPIO3 HIGH to select USB Serial/JTAG source and avoid floating strapping state |
| C_EN | 1uF 0603 | C15849 | Reset RC capacitor from EN to GND (Espressif typical EN RC with 10k pull-up) |
| SW_RESET | TL3342F160QG | C2886898 | Manual reset button |
| SW_BOOT | TL3342F160QG | C2886898 | Manual BOOT/download button |

## Before wiring
1. Open the root schematic.
2. If sheet ESP32S3Core does not exist, create a hierarchical sheet named ESP32S3Core and set its file to ESP32S3Core.
3. Open the ESP32S3Core subsheet.
4. Place U3, C_DEC, C_BULK, R_EN, R_BOOT, C_EN, SW_RESET, and SW_BOOT.
5. Do not place extra pull resistors, inductors, or experimental boot parts on this sheet.

## Pin-level wiring (connect this to that)
Use the Wire tool and connect exactly these nets:

1. 3V3 power net
- U3 3V3 supply pin -> 3V3 label
- C_BULK pin 1 -> 3V3
- C_DEC pin 1 -> 3V3
- R_EN one side -> 3V3
- R_BOOT one side -> 3V3
- R_JTAG one side -> 3V3

2. GND net
- All U3 GND pins -> GND label
- C_BULK pin 2 -> GND
- C_DEC pin 2 -> GND
- C_EN pin 2 -> GND
- SW_RESET one side -> GND
- SW_BOOT one side -> GND

3. EN reset net
- U3 EN pin -> EN_RESET net (input)
- R_EN other side -> EN_RESET
- C_EN pin 1 -> EN_RESET
- SW_RESET other side -> EN_RESET
- Add hierarchical label EN_RESET on this net (input on ESP32S3Core)

4. GPIO0 boot net
- U3 IO0 (GPIO0) pin -> GPIO0_BOOT net (input)
- R_BOOT other side -> GPIO0_BOOT
- SW_BOOT other side -> GPIO0_BOOT
- Add hierarchical label GPIO0_BOOT on this net (input on ESP32S3Core)

5. UART programming net labels
- U3 TXD0 (GPIO43) -> UART_TX label (output)
- U3 RXD0 (GPIO44) -> UART_RX label (input)

6. Fan-control net labels
- U3 IO4 (GPIO4) -> FAN_TACH label (input)
- U3 IO5 (GPIO5) -> FAN_PWM label (output)

7. Display SPI/control net labels
- U3 IO6 (GPIO6) -> SPI_SCK label (output)
- U3 IO7 (GPIO7) -> SPI_MOSI label (output)
- U3 IO9 (GPIO9) -> DISP_DC label (output)
- U3 IO10 (GPIO10) -> DISP_CS label (output)
- U3 IO16 (GPIO16) -> DISP_RST label (output)
- U3 IO40 (GPIO40) -> DISP_BL label (output)

8. GPIO3 strapping net
- U3 IO3 (GPIO3) -> R_JTAG other side
- Keep this net local to strapping support only (no functional load routing)

9. Intentionally unused pins
- Add no-connect flags only to pins you are intentionally leaving unused.
- Do not add net labels to reserved module pins.

## Label direction cheat sheet (for sheet pins)
Use this when setting hierarchical sheet-pin direction in KiCad.

1. Symbol naming reminder
- IOx on the ESP32 symbol means GPIOx.
- Example: GPIO0_BOOT connects to IO0 (not IO1).

2. Reset/boot control nets
- EN_RESET: Input on ESP32S3Core, Output on ExternalProgrammingHeader
- GPIO0_BOOT: Input on ESP32S3Core, Output on ExternalProgrammingHeader

3. UART nets
- UART_TX: Output on ESP32S3Core, Input on ExternalProgrammingHeader
- UART_RX: Input on ESP32S3Core, Output on ExternalProgrammingHeader

4. Fan nets
- FAN_PWM: Output on ESP32S3Core, Input on Fan4Wire
- FAN_TACH: Input on ESP32S3Core, Output on Fan4Wire

5. Display SPI/control nets
- SPI_SCK: Output on ESP32S3Core, Input on DisplayHeader_ST7789
- SPI_MOSI: Output on ESP32S3Core, Input on DisplayHeader_ST7789
- DISP_CS: Output on ESP32S3Core, Input on DisplayHeader_ST7789
- DISP_DC: Output on ESP32S3Core, Input on DisplayHeader_ST7789
- DISP_RST: Output on ESP32S3Core, Input on DisplayHeader_ST7789
- DISP_BL: Output on ESP32S3Core, Input on DisplayHeader_ST7789

If ERC complains in a mixed-control net, set both sides to Bidirectional as a practical fallback.

## Placement guidance (simple and practical)
1. Put U3 near a board edge so the antenna side can later keep clear of copper and metal.
2. Put C_DEC and C_BULK as close as possible to the U3 power pin area.
3. Put R_EN and C_EN close to the EN pin.
4. Put R_BOOT close to the GPIO0 pin.
5. Put SW_RESET and SW_BOOT where they are easy to press during bring-up.
6. Keep 3V3 and GND connections short between U3 and its local capacitors.

## Architecture rules you must keep
1. This sheet is powered only from 3V3, not from VIN_PROTECTED or 12V.
2. EN_RESET must be exported to ExternalProgrammingHeader for external reset/program control.
3. GPIO0_BOOT must be exported to ExternalProgrammingHeader for external boot/program control.
4. Do not route GPIO0, GPIO3, GPIO45, or GPIO46 to other functional circuits.
5. Use the fixed Rev A GPIO mapping:
- GPIO4 -> FAN_TACH
- GPIO5 -> FAN_PWM
- GPIO6 -> SPI_SCK
- GPIO7 -> SPI_MOSI
- GPIO9 -> DISP_DC
- GPIO10 -> DISP_CS
- GPIO16 -> DISP_RST
- GPIO40 -> DISP_BL
- GPIO43 -> UART_TX
- GPIO44 -> UART_RX

## Root-sheet hookup check
In the root sheet, make sure:
1. 3V3 enters this ESP32S3Core sheet from Power3V3.
2. EN_RESET and GPIO0_BOOT leave this sheet toward ExternalProgrammingHeader.
3. UART_TX and UART_RX leave this sheet toward ExternalProgrammingHeader.
4. FAN_PWM and FAN_TACH connect toward Fan4Wire.
5. SPI_SCK, SPI_MOSI, DISP_CS, DISP_DC, DISP_RST, and DISP_BL connect toward DisplayHeader_ST7789.

## Common mistakes to avoid
1. Forgetting local decoupling because the 3V3 regulator already has capacitors. The ESP32 still needs local caps on this sheet.
2. Mixing up UART direction. U3 GPIO43 is UART_TX and U3 GPIO44 is UART_RX.
3. Naming the boot/reset nets something different. They must be exactly EN_RESET and GPIO0_BOOT.
4. Putting other loads directly on GPIO0. Keep it only for the pull-up, button, and ExternalProgrammingHeader control path.
5. Reusing reserved or strapping pins for other functions.

## Final checks (2-minute checklist)
1. U3 power pins are on 3V3 and all ground pins are on GND.
2. C_BULK and C_DEC are connected between 3V3 and GND.
3. EN_RESET has a 10k pull-up to 3V3, a 1uF capacitor to GND, and a reset button to GND.
4. GPIO0_BOOT has a 10k pull-up to 3V3 and a BOOT button to GND.
5. GPIO labels match the fixed Rev A net names exactly.
6. GPIO3 has R_JTAG (10k) to 3V3 and is not routed to functional loads.
7. Reserved pins are not accidentally exported.
8. ERC runs with no real wiring errors after intentional warnings are reviewed.

## Exit criteria
- ESP32 module power and boot/reset support are complete.
- All required Rev A signal nets are exported with the correct names.
- Sheet is ready to connect to Fan4Wire, DisplayHeader_ST7789, and ExternalProgrammingHeader.

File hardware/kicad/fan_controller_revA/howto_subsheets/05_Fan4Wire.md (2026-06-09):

# Fan4Wire How-To (Beginner Version)

Target sheet: Fan4Wire

## What this sheet does
This sheet connects a standard 4-wire fan: 12V power, PWM control, and tach feedback to the ESP32.

Think of it as:
- Power in: 12V + GND
- Control in: FAN_PWM from ESP32
- Feedback out: FAN_TACH back to ESP32

## Parts to place
| RefDes | Part | LCSC | Why it is here |
|---|---|---|---|
| J_FAN | Conn_PinHeader_2.54mm_1x4 (right-angle) | C32713263 (hanxia HX PZ2.54-1x4P WZ) | 4-wire fan connector |
| Q1 | MMBT3904_Q1 | C181119 | Open-collector style PWM sink stage |
| R_BASE | 2k2 0603 | C4190 | Limits base current into Q1 |
| R_BPD | 100k 0603 | C25803 | Pull-down on base to keep Q1 off at reset |
| R_TACH_PU | 10k 0603 | C98220 | Pull-up for open-collector tach signal |
| R_TACH_SERIES | 1k 0603 | C22548 | Series protection on tach line to MCU |
| D_TACH_CLAMP | onsemi-MBR0520LT1G | C23848 | Tach clamp to 3V3 rail |
| C_FAN_BULK | 47uF 25V | C3029614 | Bulk capacitor on 12V fan rail |
| C_FAN_HF | 100nF 25V X7R 0402 | C307331 | High-frequency bypass on 12V fan rail |

## Before wiring
1. Open the root schematic.
2. If sheet Fan4Wire does not exist, create a hierarchical sheet named Fan4Wire and set its file to Fan4Wire.
3. Open the Fan4Wire subsheet.
4. Place J_FAN, Q1, R_BASE, R_BPD, R_TACH_PU, R_TACH_SERIES, D_TACH_CLAMP, C_FAN_BULK, and C_FAN_HF.

## Pin-level wiring (connect this to that)
Use the Wire tool and connect exactly these nets:

1. Fan power path
- J_FAN 12V pin -> 12V net
- J_FAN GND pin -> GND net
- C_FAN_BULK between 12V and GND
- C_FAN_HF between 12V and GND

2. PWM control path
- FAN_PWM net -> R_BASE -> Q1 base
- Q1 emitter -> GND
- Q1 collector -> J_FAN PWM pin
- R_BPD between Q1 base and GND

3. Tach feedback path
- J_FAN tach pin -> tach node
- R_TACH_PU from tach node to 3V3
- R_TACH_SERIES from tach node to FAN_TACH net
- D_TACH_CLAMP from FAN_TACH side to 3V3
- D_TACH_CLAMP orientation: cathode to 3V3, anode to FAN_TACH

4. Required labels
- Add hierarchical labels 12V, 3V3, GND, FAN_PWM, and FAN_TACH.

## Placement guidance (simple and practical)
1. Place C_FAN_BULK and C_FAN_HF close to J_FAN power pins.
2. Place Q1, R_BASE, and R_BPD close together.
3. Keep FAN_TACH conditioning parts close to each other and away from noisy 12V paths.
4. Keep GND return paths short for Q1 and fan power decoupling.

## Architecture rules you must keep
1. FAN_PWM is driven through Q1 stage, not directly to the fan pin.
2. FAN_TACH must be pulled up to 3V3.
3. Keep tach clamp direction fixed: cathode to 3V3, anode to FAN_TACH.
4. Do not power the fan from 3V3.

## Root-sheet hookup check
In the root sheet, make sure:
1. 12V enters Fan4Wire from Power12V.
2. 3V3 enters Fan4Wire for tach pull-up only.
3. FAN_PWM comes from ESP32S3Core.
4. FAN_TACH returns to ESP32S3Core.

## Common mistakes to avoid
1. Reversing tach clamp diode orientation.
2. Forgetting R_BPD on Q1 base.
3. Connecting fan power to the wrong rail.
4. Omitting local 12V decoupling at the fan connector.

## Final checks (2-minute checklist)
1. J_FAN power pins are correctly on 12V and GND.
2. Q1 stage is wired as base/emitter/collector path for PWM sink control.
3. Tach node has pull-up, series resistor, and clamp diode.
4. FAN_PWM and FAN_TACH labels are present and correct.
5. ERC has no real wiring errors for this sheet.

## Exit criteria
- Fan connector, PWM drive path, and tach return path are complete.
- Exported nets match the project naming convention.
- Sheet is ready for root integration.

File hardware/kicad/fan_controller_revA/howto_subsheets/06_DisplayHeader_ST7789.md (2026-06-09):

# DisplayHeader_ST7789 How-To (Beginner Version)

Target sheet: DisplayHeader_ST7789

## What this sheet does
This sheet exposes a simple display header for an ST7789-style SPI display, with series resistors and local decoupling.

Think of it as:
- Power in: 3V3 + GND
- Signals in/out: SPI and display control lines
- Connector out: J_DISP pins for the display cable/header

## Parts to place
| RefDes | Part | LCSC | Why it is here |
|---|---|---|---|
| J_DISP | Conn_PinHeader_2.54mm_1x8 (right-angle THT) | C32713267 | Display header interface with side cable exit |
| R_SCK R_MOSI R_CS R_DC R_RST | 33R 0603 | C2909394 | Series damping on fast digital lines |
| C_DISP_VCC | 100nF 10V 0402 | C307331 | Local display header bypass capacitor |
| Q_BL | MMBT3904 NPN SOT-23 | C181119 | Open-collector backlight sink stage |
| R_BL_BASE | 2.2k 0603 | C4190 | Base current limit for Q_BL |
| R_BL_PD | 100k 0603 | C25803 | Base pull-down so BL stage defaults off |

## Before wiring
1. Open the root schematic.
2. If sheet DisplayHeader_ST7789 does not exist, create a hierarchical sheet named DisplayHeader_ST7789 and set its file to DisplayHeader_ST7789.
3. Open the DisplayHeader_ST7789 subsheet.
4. Place J_DISP, R_SCK, R_MOSI, R_CS, R_DC, R_RST, C_DISP_VCC, Q_BL, R_BL_BASE, and R_BL_PD.

## Pin-level wiring (connect this to that)
Use the Wire tool and connect exactly these nets:

1. Power pins
- J_DISP VCC pin -> 3V3
- J_DISP GND pin -> GND
- C_DISP_VCC between 3V3 and GND near J_DISP

2. SPI/control lines through series resistors
- SPI_SCK -> R_SCK -> J_DISP SCK pin
- SPI_MOSI -> R_MOSI -> J_DISP MOSI pin
- DISP_CS -> R_CS -> J_DISP CS pin
- DISP_DC -> R_DC -> J_DISP DC pin
- DISP_RST -> R_RST -> J_DISP RST pin

3. MISO policy for Rev A
- Leave J_DISP MISO/SDO pin unconnected (NC)

4. Backlight open-collector stage (fan-style)
- DISP_BL -> R_BL_BASE -> Q_BL base
- Q_BL base -> R_BL_PD -> GND
- Q_BL emitter -> GND
- Q_BL collector -> J_DISP BLK pin
- Use ESP32 GPIO40 PWM on DISP_BL to dim the backlight through Q_BL sink action

5. Required labels
- Add hierarchical labels: 3V3, GND, SPI_SCK, SPI_MOSI, DISP_CS, DISP_DC, DISP_RST, DISP_BL

## Placement guidance (simple and practical)
1. Place series resistors close to the header or in a tight grouped row.
2. Place C_DISP_VCC close to J_DISP VCC/GND pins.
3. Keep SPI/control traces short and parallel routing clean.

## Architecture rules you must keep
1. Use the fixed display net names from the project mapping.
2. Do not implement SPI_MISO on Rev A.
3. Do not power the display from 12V.

## Root-sheet hookup check
In the root sheet, make sure:
1. SPI and control nets come from ESP32S3Core.
2. 3V3 and GND are provided from the power/ground backbone.
3. Net names match exactly between this sheet and ESP32S3Core.

## Common mistakes to avoid
1. Bypassing the series resistors by wiring nets directly to J_DISP pins.
2. Mixing DISP_DC and DISP_RST labels.
3. Forgetting local VCC bypass at the header.
4. Accidentally routing display MISO/SDO into the MCU on Rev A.
5. Wiring BLK directly to DISP_BL and bypassing Q_BL.

## Final checks (2-minute checklist)
1. All required SPI/control lines are wired through the correct series resistors.
2. J_DISP has 3V3 and GND plus local 100nF bypass.
3. Label names match project conventions exactly.
4. ERC has no real wiring errors for this sheet.

## Exit criteria
- Display header and control interface are complete and labeled.
- Rev A no-MISO decision is explicit.
- Sheet is ready for root integration.

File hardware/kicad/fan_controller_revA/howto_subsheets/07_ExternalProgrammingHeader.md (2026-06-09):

# ExternalProgrammingHeader How-To (Beginner Version)

Target sheet: ExternalProgrammingHeader

## What this sheet does
This sheet exposes a simple external programming/debug connector for the ESP32.

Think of it as:
- Connector out: 1x6 programming header
- Signals in/out: UART + reset/boot control + power/ground reference

## Parts to place
| RefDes | Part | LCSC | Why it is here |
|---|---|---|---|
| J_PROG | Conn_PinHeader_2.54mm_1x6 (right-angle THT) | C42453955 | External programming/debug interface with side cable exit |

## Before wiring
1. Open the root schematic.
2. If sheet ExternalProgrammingHeader does not exist, create a hierarchical sheet named ExternalProgrammingHeader and set its file to ExternalProgrammingHeader.
3. Open the ExternalProgrammingHeader subsheet.
4. Place J_PROG.

## Pin-level wiring (connect this to that)
Use the Wire tool and connect exactly these nets:

1. Header pins
- J_PROG pin 1 -> GND
- J_PROG pin 2 -> 3V3
- J_PROG pin 3 -> UART_TX
- J_PROG pin 4 -> UART_RX
- J_PROG pin 5 -> EN_RESET
- J_PROG pin 6 -> GPIO0_BOOT

2. Required labels
- Add hierarchical labels: 3V3, GND, UART_TX, UART_RX, EN_RESET, GPIO0_BOOT

## External adapter mapping note
Document this mapping in bring-up notes:
- adapter RX -> UART_TX
- adapter TX -> UART_RX
- adapter reset control -> EN_RESET (optional)
- adapter boot control -> GPIO0_BOOT (optional)

## Architecture rules you must keep
1. Keep EN_RESET and GPIO0_BOOT active-low behavior unchanged.
2. Do not rename UART_TX/UART_RX nets.
3. Leave BOOT and RESET buttons on ESP32 sheet for manual flashing fallback.
4. Do not add on-board USB-UART circuitry in this sheet.

## Root-sheet hookup check
In the root sheet, make sure:
1. ESP32S3Core UART_TX/UART_RX connect to ExternalProgrammingHeader UART_TX/UART_RX.
2. ESP32S3Core EN_RESET/GPIO0_BOOT connect to ExternalProgrammingHeader EN_RESET/GPIO0_BOOT.
3. 3V3 and GND are provided from main rails.

## Common mistakes to avoid
1. Swapping UART_TX and UART_RX.
2. Reversing EN_RESET and GPIO0_BOOT control lines.
3. Missing pin-1 indicator or unreadable silkscreen labels.

## Final checks (2-minute checklist)
1. All six nets are present and labeled correctly.
2. Header pin order matches intended cable convention.
3. ERC has no real wiring errors for this sheet.

## Exit criteria
- External programming interface is complete and unambiguous.
- Sheet is ready for root integration.

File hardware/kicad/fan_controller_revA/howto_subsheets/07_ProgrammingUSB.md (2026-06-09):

# ProgrammingUSB How-To (Archived Reference)

Target sheet: ProgrammingUSB (archived)

## Status
This guide is archived and kept only as historical reference for the old on-board USB-UART concept.

Active Rev A programming interface:
- Use [07_ExternalProgrammingHeader.md](07_ExternalProgrammingHeader.md)

## Notes
- Do not delete this file.
- Do not use this file for active root-sheet integration in Rev A.

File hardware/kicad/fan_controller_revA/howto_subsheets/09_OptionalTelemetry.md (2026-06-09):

# OptionalTelemetry How-To (Deferred for Rev A)

Target sheet: future revision only

## What this sheet does
This sheet is reserved for future telemetry features. It is not part of active Rev A capture.

Think of it as:
- Rev A: do not capture
- Future revision: optional diagnostics connector with clear net ownership

## Current Rev A rule
OptionalTelemetry is deferred from Rev A.

Do not add this sheet to the active Rev A root hierarchy. If bring-up later proves telemetry is needed, add it in a new revision with a fresh GPIO and BOM review.

## Future parts to place (only if enabled)
1. Telemetry connector/header
2. Optional line protection or series resistors
3. Optional pull-ups if I2C is used and this sheet owns them

## Future wiring template (only if enabled)
1. Power pins
- 3V3
- GND

2. Interface choice
- I2C option: SDA + SCL
- UART option: TX + RX
- Or both, if you explicitly allocate pins and labels

3. Labeling
- Add hierarchical labels for every exported telemetry net
- Use explicit direction in naming and documentation

## Architecture rules you must keep
1. Do not consume reserved/boot-critical pins.
2. Do not overload existing mandatory interfaces.
3. Keep telemetry optional and removable for production builds.

## Exit criteria (future revision only)
- Telemetry interface is fully labeled and documented.
- ERC has no real wiring errors.
- Net ownership and GPIO assignment are reviewed before merge.

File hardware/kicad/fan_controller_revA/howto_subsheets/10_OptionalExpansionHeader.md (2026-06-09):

# OptionalExpansionHeader How-To (Beginner Version)

Target sheet: OptionalExpansionHeader

## What this sheet does
This sheet exposes a protected 3V3/GND expansion header and a small set of safe GPIOs for future add-ons.

Think of it as:
- Power out: 3V3 through a polyfuse + GND
- GPIO out: a selected set of non-boot-critical ESP32 pins

## Parts to place
| RefDes | Part | LCSC | Why it is here |
|---|---|---|---|
| J_EXP | PZ2.54-2X5P-H25 | C42431818 | Expansion header connector |
| R_EXP1 R_EXP2 R_EXP3 R_EXP4 R_EXP5 R_EXP6 R_EXP7 R_EXP8 | 33R 0603 | C2909394 | Series protection/damping on expansion GPIO lines |
| F_EXP | 0805L050WR | C207022 | Polyfuse on exported 3V3 power |

## Before wiring
1. Open the root schematic.
2. If sheet OptionalExpansionHeader does not exist, create a hierarchical sheet named OptionalExpansionHeader and set its file to OptionalExpansionHeader.
3. Open the OptionalExpansionHeader subsheet.
4. Place J_EXP, F_EXP, and eight series resistors R_EXP1 to R_EXP8.

## Pin-level wiring (connect this to that)
Use the Wire tool and connect exactly these nets:

1. Expansion power pins
- 3V3 -> F_EXP -> J_EXP power pin
- GND -> J_EXP ground pin

2. Expansion GPIO signals
- Use only these Rev A expansion nets:
- GPIO17
- GPIO18
- GPIO19
- GPIO20
- GPIO21
- GPIO38
- GPIO39
- GPIO41
- Route each signal through one 33R resistor before J_EXP pin

3. Required labels
- Add net labels for each exported GPIO line
- Add hierarchical labels for all exported expansion nets

## Placement guidance (simple and practical)
1. Put J_EXP near board edge for easy access.
2. Keep F_EXP close to the 3V3 entry to the header power pin.
3. Keep resistor bank close to the header for clean routing.

## Architecture rules you must keep
1. Do not export boot-critical or reserved GPIO pins.
2. Keep 3V3 export behind F_EXP polyfuse.
3. Preserve exact net naming from project GPIO map.

## Root-sheet hookup check
In the root sheet, make sure:
1. 3V3 and GND are connected from system rails.
2. Expansion GPIO nets originate from the intended ESP32S3Core nets.
3. No duplicate or conflicting GPIO exports are created.

## Common mistakes to avoid
1. Exporting GPIO0, GPIO3, GPIO45, or GPIO46.
2. Forgetting polyfuse on expansion 3V3.
3. Bypassing series resistors on expansion GPIO lines.

## Final checks (2-minute checklist)
1. J_EXP has fused 3V3 and GND pins wired.
2. Exactly eight approved GPIO lines are exported through 33R resistors.
3. Net labels and hierarchical labels match the project naming.
4. ERC has no real wiring errors for this sheet.

## Exit criteria
- Expansion header power and GPIO lines are complete and safe.
- Exported nets match Rev A constraints.
- Sheet is ready for root integration.

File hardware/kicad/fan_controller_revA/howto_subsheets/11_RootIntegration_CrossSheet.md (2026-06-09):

# Root Integration and Cross-Sheet How-To (Beginner Version)

Target sheet: fan_controller_revA

## What this step does
This is where all finished subsheets are connected together at top level.

Think of it as:
- Power backbone: InputProtection -> Power12V/Power3V3 -> loads
- Signal backbone: ESP32S3Core <-> Fan/Display/ExternalProgramming sheets

## Before wiring
1. Open the root sheet.
2. If the root page is messy or from a failed import, remove clutter and place fresh sheet symbols manually.
3. Arrange sheets in a left-to-right flow:
- InputProtection on left
- Power12V and Power3V3 center-left
- ESP32S3Core center
- Fan4Wire, DisplayHeader_ST7789, ExternalProgrammingHeader, and optional sheets on right
4. For each sheet symbol, run Sync Sheet Pins so root pins match child labels.

## Net-level wiring (connect this to that)
Use the Wire tool and connect exactly these root nets:

1. Power rails
- VIN_PROTECTED from InputProtection -> Power12V VIN_PROTECTED
- VIN_PROTECTED from InputProtection -> Power3V3 VIN_PROTECTED
- 12V from Power12V -> Fan4Wire 12V
- 3V3 from Power3V3 -> ESP32S3Core
- 3V3 from Power3V3 -> DisplayHeader_ST7789
- 3V3 from Power3V3 -> ExternalProgrammingHeader
- 3V3 from Power3V3 -> Fan4Wire pull-up rail
- GND shared across all sheets

2. Fan-control interface
- ESP32S3Core FAN_PWM -> Fan4Wire FAN_PWM
- Fan4Wire FAN_TACH -> ESP32S3Core FAN_TACH

3. Display interface
- ESP32S3Core SPI_SCK -> DisplayHeader_ST7789 SPI_SCK
- ESP32S3Core SPI_MOSI -> DisplayHeader_ST7789 SPI_MOSI
- Mapping update: DISP_DC is on GPIO9, DISP_CS is on GPIO10, DISP_RST is on GPIO16, DISP_BL is on GPIO40
- ESP32S3Core DISP_CS -> DisplayHeader_ST7789 DISP_CS
- ESP32S3Core DISP_DC -> DisplayHeader_ST7789 DISP_DC
- ESP32S3Core DISP_RST -> DisplayHeader_ST7789 DISP_RST
- ESP32S3Core DISP_BL -> DisplayHeader_ST7789 DISP_BL

4. Programming interface
- ESP32S3Core UART_TX -> ExternalProgrammingHeader UART_TX
- ExternalProgrammingHeader UART_RX -> ESP32S3Core UART_RX
- ExternalProgrammingHeader EN_RESET -> ESP32S3Core EN_RESET
- ExternalProgrammingHeader GPIO0_BOOT -> ESP32S3Core GPIO0_BOOT

## Cross-sheet consistency rules
1. Root net names must exactly match child-sheet pin names.
2. Do not create duplicate names for the same signal with alternate spellings.
3. Keep optional-sheet nets isolated unless intentionally connected.

## Common mistakes to avoid
1. Forgetting Sync Sheet Pins after child-sheet edits.
2. Wiring VIN_PROTECTED in series through power sheets instead of parallel feed.
3. Mismatched net spellings between root and child sheets.
4. Leaving orphan sheet pins unconnected by accident.

## Final checks (2-minute checklist)
1. Every exported child label has a matching root sheet pin.
2. No orphan pins remain on root sheet symbols.
3. Power rails are connected in the intended topology.
4. Root ERC runs and only intentional warnings remain.

## Exit criteria
- Root sheet is fully wired and readable.
- Cross-sheet pin syncing is clean.
- Whole-project ERC has no unresolved real errors.

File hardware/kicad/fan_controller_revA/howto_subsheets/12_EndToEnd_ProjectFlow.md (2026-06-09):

# End-to-End Schematic Capture How-To (Beginner Version)

Scope: complete project flow from blank subsheets to commit-ready schematic.

## What this guide does
This guide gives you one linear checklist from project setup to final commit.

Think of it as:
- Build sheets one by one
- Validate each sheet locally
- Integrate at root
- Run full ERC and lock

## Quick net naming rules (use exactly these)
- VIN_PROTECTED
- 12V
- 3V3
- GND
- FAN_PWM
- FAN_TACH
- UART_TX
- UART_RX
- EN_RESET
- GPIO0_BOOT
- SPI_SCK
- SPI_MOSI
- DISP_CS
- DISP_DC
- DISP_RST
- DISP_BL

## Quick LCSC reference
1. InputProtection: F1 C3105, D1 C16015, D_TVS_IN C135062, C_IN_BULK C72480
2. Power12V: U1 C5369648, caps C72480/C15849/C3029614/C307331
3. Power3V3: U2 C50396472, caps C72480/C380537/C2887276/C92487
4. Core interfaces: ESP32-S3 module C2913202, external programming header, tach clamp C23848

## Phase 1: project preparation
1. Open project in KiCad and confirm there are no parse errors.
2. Set grid to 50 mil for symbol capture.
3. Create or verify root-sheet skeleton.
4. Ensure sheet names and file names match the how-to files exactly.

## Phase 2: subsheet capture order
1. Complete 01_InputProtection.md
2. Complete 02_Power12V.md
3. Complete 03_Power3V3.md
4. Complete 05_Fan4Wire.md
5. Complete 06_DisplayHeader_ST7789.md
6. Complete 07_ExternalProgrammingHeader.md
7. Complete 08_TestPoints.md
8. Complete 10_OptionalExpansionHeader.md only if needed
9. Complete 04_ESP32S3Core.md last, after signal names are fixed

Archived reference:
- 07_ProgrammingUSB.md remains for historical reference only and is not part of active Rev A integration.

Rule during this phase:
- Run sheet-level local sanity checks after each sheet.

## Phase 3: root integration
1. Follow 11_RootIntegration_CrossSheet.md.
2. Sync sheet pins for every subsheet.
3. Wire power and signal backbones at root.
4. Run full-project ERC and fix real errors.

## Phase 4: part-data quality gate
1. Annotate all symbols.
2. Fill required fields:
- Value
- Footprint
- MPN
- LCSC part number
- Datasheet URL
3. Verify critical pinouts and footprints against datasheets.

## Phase 5: pre-PCB gate
1. Assign footprints to all symbols.
2. Check package orientation and pin-1 assumptions.
3. Re-run ERC after footprint updates.
4. Save project and create a dated backup snapshot.

## Phase 6: commit-ready finish
1. Review working tree and keep only intended files.
2. Run final full-project ERC and export report.
3. Commit with a clear message.

## Common mistakes to avoid
1. Using inconsistent net names between sheets.
2. Skipping Sync Sheet Pins after child-sheet changes.
3. Running only standalone-sheet ERC and assuming integration is clean.
4. Committing generated lock/history/report artifacts.

## Final checks (2-minute checklist)
1. All required subsheets are captured and integrated.
2. Root-sheet nets are consistent with child-sheet labels.
3. Full-project ERC has no unresolved real errors.
4. Footprints and core part metadata are complete.
5. Git status contains only intentional changes.

## Done definition
1. Schematic is capture-complete.
2. Cross-sheet wiring is validated.
3. ERC is clean or only has justified warnings.
4. Project is commit-ready and documented.

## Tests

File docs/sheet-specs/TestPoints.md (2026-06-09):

# Sheet Spec: TestPoints

**KiCad sheet:** `TestPoints`  
**Purpose:** Labeled test point pads for bring-up, debugging, and production verification. No active components. Must not alter any net behavior.  
**Rule:** Every test point is a passive net tap only — no added series resistance, no pull-up/pull-down, no load.

---

## Test Point List

| Ref | Net | Label | Signal type | Notes |
|-----|-----|---|---|---|
| TP1 | VIN_PROTECTED | VIN | DC power | After input protection; pre-module input |
| TP2 | 12V | 12V | DC power | K7812 module output |
| TP3 | 3V3 | 3V3 | DC power | K7803 module output |
| TP4 | GND | GND | Ground | Common reference (multiple pads OK) |
| TP5 | FAN_PWM | FAN_PWM | 3.3V PWM logic | ESP32 GPIO5 output |
| TP6 | FAN_TACH | FAN_TACH | 3.3V logic | Conditioned tach input to ESP32 GPIO4 |
| TP7 | EN_RESET | EN | 3.3V logic | ESP32-S3 EN pin |
| TP8 | GPIO0_BOOT | BOOT | 3.3V logic | ESP32-S3 GPIO0 |
| TP9 | UART_TX | TX | 3.3V UART | ESP32 TX (GPIO43) |
| TP10 | UART_RX | RX | 3.3V UART | ESP32 RX (GPIO44) |

Rev A default decision:
- TP11 (DISP_BL) is deferred to Rev B to avoid scope/routing churn. Re-open only if verified board space is available with no routing risk.

---

## Test Point Footprint

| Parameter | Value |
|---|---|
| Pad size | 1.0mm drill, 1.5mm copper ring (through-hole) |
| Preferred type | Keystone 5000 or equivalent 1.0mm THT test point | 
| Alternate | SMD pad 1.5×1.5mm with silkscreen label (no height for probe but compact) |
| Assembly | PCBWay can insert THT test points; SMD pads require no assembly and cost less |

**Recommendation:** Use SMD test point pads (no component, just copper pad + silkscreen label) for power and logic rails. This reduces BOM cost and assembly complexity. A probe tip can contact the pad directly.

---

## Placement Guidelines

1. **Power rail test points (TP1–TP4):** Place near each rail's output cap — allows confirming rail is good before probing logic.
2. **Logic test points (TP5–TP10):** Place near the ESP32 module edge, in a row for easy logic analyzer clip attachment.
3. **Multiple GND pads:** Place at least 2–3 GND test points distributed near other test points so every probe can find a nearby return.
4. **All test points must be accessible from top-side probe** — do not place under headers or module.

---

## Silkscreen Requirements

Each test point pad must have:
- Ref designator (TP1, TP2…)
- Net name label (VIN, 12V, 3V3, GND, FAN_PWM, etc.)

---

## Dependencies

- **Depends on:** all mandatory sheets (uses only existing nets, adds no new components that affect behavior)
- **Consumed by:** none (leaf sheet)
- **Capture order:** last mandatory sheet, after all other functional sheets are captured

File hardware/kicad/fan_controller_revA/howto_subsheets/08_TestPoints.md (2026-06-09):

# TestPoints How-To (Beginner Version)

Target sheet: TestPoints

## What this sheet does
This sheet adds easy probe points for bring-up and troubleshooting.

Think of it as:
- Power test pads: VIN_PROTECTED, 12V, 3V3, GND
- Signal test pads: boot/reset, UART, and fan control feedback

## Parts to place
This sheet is test pads only in Rev A, so there are no locked LCSC BOM lines required for capture.

## Before wiring
1. Open the root schematic.
2. If sheet TestPoints does not exist, create a hierarchical sheet named TestPoints and set its file to TestPoints.
3. Open the TestPoints subsheet.
4. Place ten test-point symbols and name them TP1 through TP10.

## Pin-level wiring (connect this to that)
Use the Wire tool and connect exactly these nets:

1. Power test points
- TP1 -> VIN_PROTECTED
- TP2 -> 12V
- TP3 -> 3V3
- TP4 -> GND

2. Control and programming test points
- TP5 -> FAN_PWM
- TP6 -> FAN_TACH
- TP7 -> UART_TX
- TP8 -> UART_RX
- TP9 -> EN_RESET
- TP10 -> GPIO0_BOOT

3. Labeling
- Place readable text labels near each TP so probing is obvious on printouts and screenshots.

## Placement guidance (simple and practical)
1. Put power test points near board edges with enough probe clearance.
2. Keep TP4 GND in an easy-to-reach position for oscilloscope ground clips.
3. Group related digital test points together.

## Architecture rules you must keep
1. Test points are measurement taps only, not routing hubs.
2. Do not rename nets at this sheet.
3. Keep the same net names used by source sheets.

## Root-sheet hookup check
In the root sheet, make sure:
1. TestPoints sheet pins match the ten nets listed above.
2. No duplicate or misspelled net names exist.

## Common mistakes to avoid
1. Swapping UART_TX and UART_RX labels.
2. Forgetting a dedicated GND test point.
3. Creating a new net by typo instead of connecting to the existing one.

## Final checks (2-minute checklist)
1. All ten test points are present and uniquely labeled.
2. Each test point is wired to the intended net.
3. ERC has no real wiring errors for this sheet.

## Exit criteria
- Critical power and debug nets are accessible by probe.
- TestPoints sheet is ready for root integration.

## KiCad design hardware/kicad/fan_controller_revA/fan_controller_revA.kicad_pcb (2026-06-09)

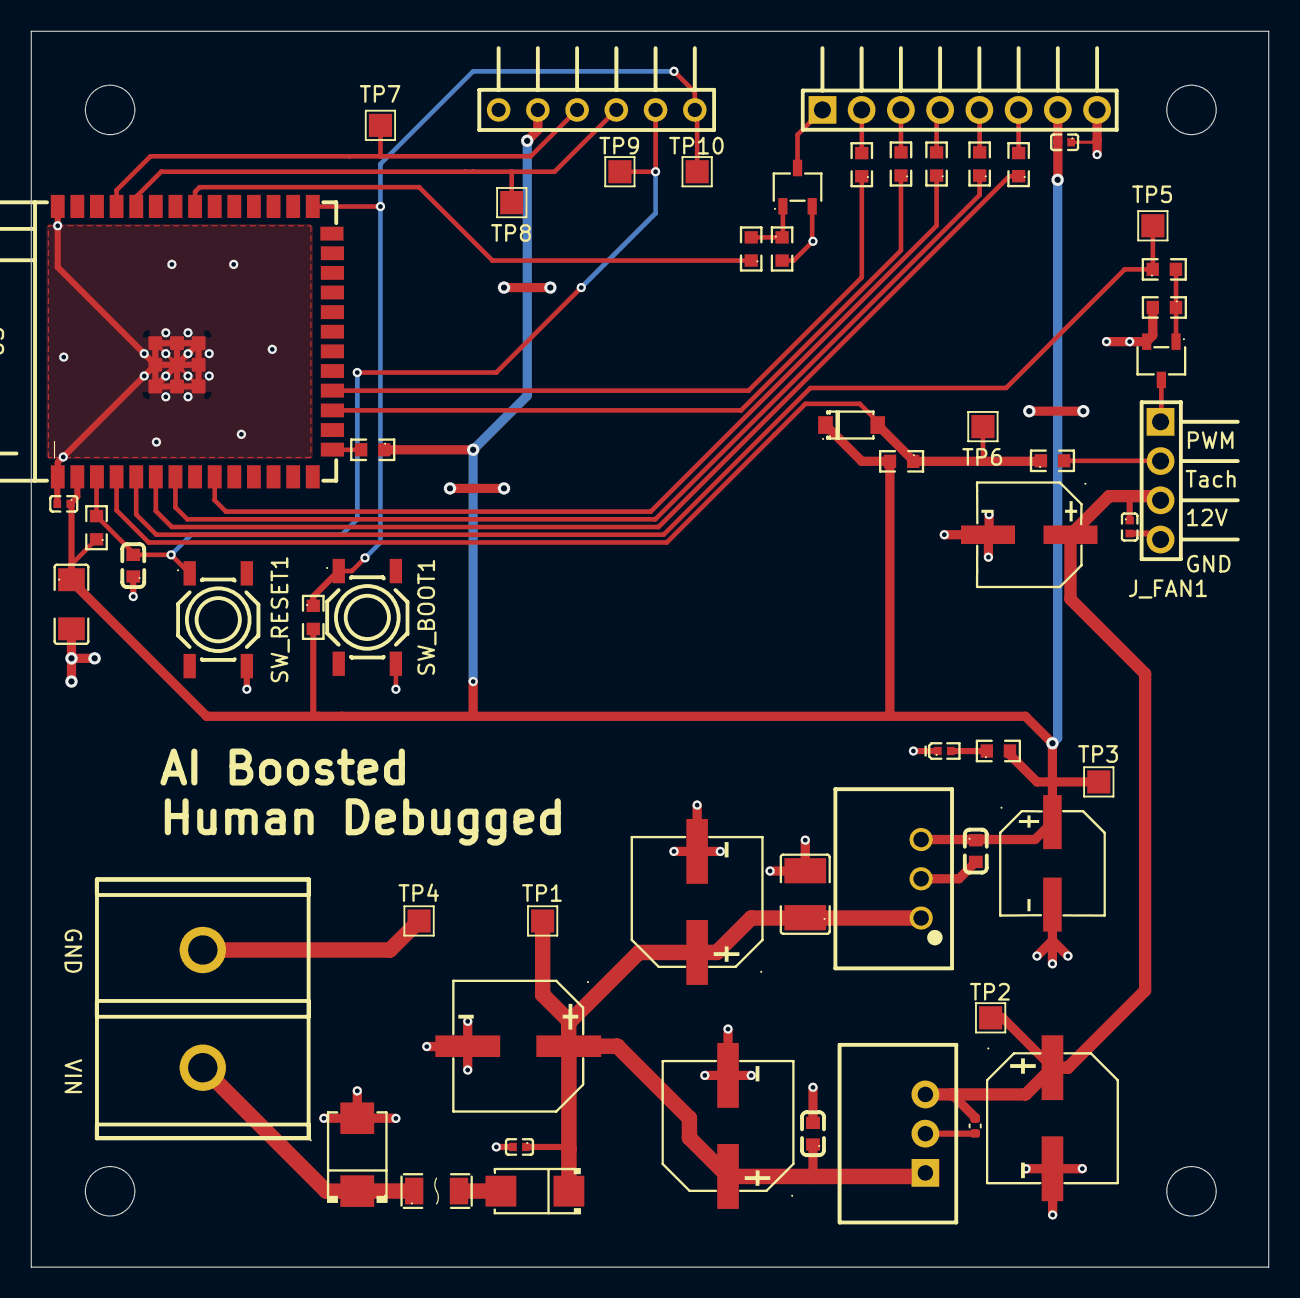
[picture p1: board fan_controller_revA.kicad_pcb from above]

Board: 2 copper layers, 80.1 x 80.0 mm, 57 parts (0 on the bottom side), 30 nets.

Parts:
C12_IN_BULK1, C33_IN_BULK1: 100uF 50V ±20%; C72480_CAP-SMD_BD8_0-L8_3-W8_3-FD
C12_IN_BYP1: 1uF (105) ±10% 50V; C15849_C0603
C12_OUT_BULK1: 47uF 25V; C72480_CAP-SMD_BD8_0-L8_3-W8_3-FD
C12_OUT_BYP1: 100nF 50V X7R; C_0402_1005Metric
C33_IN_BYP1: CL32A106KBJNNNE; C380537_C1210
C33_OUT_BULK1: RVT100UF16V67RV0016; C2887276_CAP-SMD_BD6_3-L6_6-W6_6-LS7_2-FD
C33_OUT_BYP1: CL10A106MO8NQNC; C92487_C0603
C_BULK1: 22uF（226）±10% 16V; C90146_C1206
C_DEC1: CL05B104KB54PNC; C307331_C0402
C_DISP_VCC1: CL05B104KB54PNC; C307331_C0402
C_EN1: 1uF/50V X7R; C15849_C0603
C_FAN_BULK1: VUA470M1ETR-0607; C3029614_CAP-SMD_BD6_3-L6_6-W6_6-FD
C_FAN_HF1: CL05B104KB54PNC; C307331_C0402
C_IN_BULK1: 100uF 50V ±20%; C72480_CAP-SMD_BD8_0-L8_3-W8_3-FD
C_IN_BYP1: CL05B104KB54PNC; C307331_C0402
D1: SS36; C16015_SMA_L4_3-W2_6-LS5_2-RD
D_TACH_CLAMP1: MBR0520LT1G; C23848_SOD-123_L2_8-W1_8-LS3_7-RD
D_TVS_IN1: SMBJ26A-13-F; C135062_SMB_L4_6-W3_6-LS5_3-RD
F1: 2A 63V; C3105_F1206
J_DISP1: HX PZ2.54-1X8P WZ; C32713267_HDR-TH_8P-P2_54-H-M-W10_3
J_FAN1: HX PZ2.54-1X4P WZ; C32713263_HDR-TH_4P-P2_54-H-M-W10_3
J_PROG1: HX PZ2.54-1X6P WZ-P; C42453955_HDR-TH_6P-P2_54-H-M_DS1022-1X6RUF11-B
J_PWR1: DBT30C-7.62-2P; C395939_CONN-TH_2P-P7_62_DBT30C-7_62-2P
LED_POWER2: FC-F1005UGK-520M5; C130723_LED0402-RD
Q1: MMBT3904_C181119; C181119_SOT-23-3_L2_9-W1_6-P1_90-LS2_8-BR
Q_BL1: MMBT3904_C181119; C181119_SOT-23-3_L2_9-W1_6-P1_90-LS2_8-BR
R_BASE1: 2.2KΩ (2201) ±1%; C4190_R0603
R_BL_BASE1: 2.2KΩ (2201) ±1%; C4190_R0603
R_BL_PD1: 100KΩ (1003) ±1%; C25803_R0603
R_BOOT1: 10KΩ (1002) ±1%; C25804_R0603
R_BPD1: 100KΩ (1003) ±1%; C25803_R0603
R_CS1: FRC0603F33R0TS; C2909394_R0603
R_DC1: FRC0603F33R0TS; C2909394_R0603
R_EN1: 10KΩ (1002) ±1%; C25804_R0603
R_JTAG1: RC0603JR-0710KL; C99198_R0603
R_LED_PWR2: 1KΩ (1001) ±1%; C22548_R0603
R_MOSI1: FRC0603F33R0TS; C2909394_R0603
R_RST3: FRC0603F33R0TS; C2909394_R0603
R_SCK1: FRC0603F33R0TS; C2909394_R0603
R_TACH_PU1: RC0603FR-0710KL; C98220_R0603
R_TACH_SERIES1: 1KΩ (1001) ±1%; C22548_R0603
SW_BOOT1: TL3342F160QG; C2886898_SW-SMD_4P-L5_2-W5_2-P3_70-LS6_4-BL
SW_RESET1: TL3342F160QG; C2886898_SW-SMD_4P-L5_2-W5_2-P3_70-LS6_4-BL
TP1, TP2, TP3, TP4, TP5, TP6, TP7, TP8, TP9, TP10: TestPoint; TestPoint_Pad_1.5x1.5mm
U1: K7812-1000R3_C5369648; C5369648_PWRM-TH_K7812-1000R3
U2: K7803-1000R3_C5369647; C5369647_PWRM-TH_YLPTEC_K78XX-1000R3
U3: ESP32-S3-WROOM-1(N16R8); C2913202_WIRELM-SMD_ESP32-S3-WROOM-1

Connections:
/DisplayHeader_ST7789/3V3: C33_OUT_BULK1.1, C33_OUT_BYP1.1, C_BULK1.1, C_DEC1.1, C_DISP_VCC1.2, D_TACH_CLAMP1.1 (C), J_DISP1.7, J_PROG1.5, R_BOOT1.2, R_EN1.1, R_JTAG1.1, R_LED_PWR2.2, R_TACH_PU1.2, TP3.1 (1_1), U2.3 (+Vo), U3.2 (3V3)
/DisplayHeader_ST7789/BLK_Header: J_DISP1.1, Q_BL1.3
/DisplayHeader_ST7789/DISP_BL: R_BL_BASE1.1, U3.33 (IO40)
/DisplayHeader_ST7789/DISP_CS: R_CS1.1, U3.18 (IO10)
/DisplayHeader_ST7789/DISP_DC: R_DC1.1, U3.17 (IO9)
/DisplayHeader_ST7789/DISP_RST: R_RST3.1, U3.9 (IO16)
/DisplayHeader_ST7789/SPI_MOSI: R_MOSI1.1, U3.7 (IO7)
/DisplayHeader_ST7789/SPI_SCK: R_SCK1.1, U3.6 (IO6)
/ESP32S3Core/EN_RESET: C_EN1.2, J_PROG1.2, R_EN1.2, SW_RESET1.1, TP9.1 (1_1), U3.3 (EN)
/ESP32S3Core/FAN_PWM: R_BASE1.1, TP5.1 (1_1), U3.5 (IO5)
/ESP32S3Core/FAN_TACH: D_TACH_CLAMP1.2 (A), R_TACH_PU1.1, R_TACH_SERIES1.1, TP6.1 (1_1), U3.4 (IO4)
/ESP32S3Core/GPIO0_BOOT: J_PROG1.1, R_BOOT1.1, SW_BOOT1.1, TP10.1 (1_1), U3.27 (IO0)
/ESP32S3Core/UART_RX: J_PROG1.3, TP8.1 (1_1), U3.36 (RXD0)
/ESP32S3Core/UART_TX: J_PROG1.4, TP7.1 (1_1), U3.37 (TXD0)
/Fan4Wire/12V: C12_OUT_BULK1.1, C12_OUT_BYP1.1, C_FAN_BULK1.1, C_FAN_HF1.1, J_FAN1.3, TP2.1 (1_1), U1.3 (+Vo/GND)
/InputProtection/VIN_FUSED: D1.2 (A), F1.2
/InputProtection/VIN_PROTECTED: C12_IN_BULK1.1, C12_IN_BYP1.1, C33_IN_BULK1.1, C33_IN_BYP1.1, C_IN_BULK1.1, C_IN_BYP1.1, D1.1 (K), TP1.1 (1_1), U1.1 (Vin), U2.1 (Vin)
/InputProtection/VIN_RAW: D_TVS_IN1.1 (K), F1.1, J_PWR1.1
GND: C12_IN_BULK1.2, C12_IN_BYP1.2, C12_OUT_BULK1.2, C12_OUT_BYP1.2, C33_IN_BULK1.2, C33_IN_BYP1.2, C33_OUT_BULK1.2, C33_OUT_BYP1.2, C_BULK1.2, C_DEC1.2, C_DISP_VCC1.1, C_EN1.1, C_FAN_BULK1.2, C_FAN_HF1.2, C_IN_BULK1.2, C_IN_BYP1.2, D_TVS_IN1.2 (A), J_DISP1.8, J_FAN1.4, J_PROG1.6, J_PWR1.2, LED_POWER2.1 (K), Q1.2, Q_BL1.2, R_BL_PD1.2, R_BPD1.2, SW_BOOT1.4, SW_RESET1.4, TP4.1 (1_1), U1.2 (GND/-Vo), U2.2 (GND), U3.1 (GND), U3.40 (GND), U3.41 (GND)
unnamed: J_DISP1.2, R_CS1.2
unnamed: J_DISP1.3, R_DC1.2
unnamed: J_DISP1.4, R_RST3.2
unnamed: J_DISP1.5, R_MOSI1.2
unnamed: J_DISP1.6, R_SCK1.2
unnamed: J_FAN1.1, Q1.3
unnamed: J_FAN1.2, R_TACH_SERIES1.2
unnamed: LED_POWER2.2 (A), R_LED_PWR2.1
unnamed: Q1.1, R_BASE1.2, R_BPD1.1
unnamed: Q_BL1.1, R_BL_BASE1.2, R_BL_PD1.1
unnamed: R_JTAG1.2, U3.15 (IO3)
